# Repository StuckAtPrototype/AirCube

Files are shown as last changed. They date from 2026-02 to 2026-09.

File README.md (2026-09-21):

# AirCube

**See your air.** AirCube is a desktop air quality monitor with built-in **Home Assistant** support over **Zigbee** or **Bluetooth (BLE)**. Every model tracks temperature, humidity, eCO2, eTVOC, and VOC Level; AirCube Pro also measures true CO2 and ambient light. A glanceable LED shows the current air quality.

Works standalone out of the box. Pairs with Home Assistant in minutes. Other platforms are supported through **[community-contributed extensions](#community-extensions)**.

[AirCube Web](https://stuckatprototype.github.io/AirCube/) -- Live readings, history and firmware updates in your browser. Nothing to install.

[Watch the overview](https://www.youtube.com/watch?v=a4EFVtmDL8s) -- What AirCube does and why it's open source, in under three minutes.

[StuckAtPrototype Labs](https://www.youtube.com/@StuckAtPrototypeLabs) -- Step-by-step video walkthroughs: [ZHA setup](https://www.youtube.com/watch?v=rpkR3O64rY8), [Zigbee2MQTT setup](https://www.youtube.com/watch?v=eybU8-ZFDcc), and [updating firmware from the browser](https://www.youtube.com/watch?v=4XfEABJolAE).

[AirCube](https://stuckatprototype.com/products/aircube) -- Assembled AirCube

[AirCube Populated PCB](https://stuckatprototype.com/products/aircube-populated-pcb) -- AirCube Populated PCB

---

## Getting Started

**1. Plug it in** -- Connect the USB-C cable to any USB port or charger. AirCube powers on automatically.

**2. Wait for warm-up** -- The air quality sensor needs about 3 minutes to stabilize after power-on. During this time, the LED may not reflect accurate readings.

**3. Read the color** -- Once warmed up, the LED tells you everything:

| LED Color | Air Quality |
|---|---|
| Green | Good |
| Yellow | Moderate |
| Orange | Poor |
| Red | Bad -- consider ventilating |

The color shifts smoothly as conditions change. No app needed -- just glance at it.

> **Firmware 1.5.0 and above** drive the LED from **canonical VOC Level** (TVOC-derived, absolute). The color is a smooth green-to-red gradient -- same feel as older firmware, but tied to fixed indoor-air bands instead of the relative AQI-S baseline. See **[LED Reference](#led-reference)** for the exact mapping. Firmware **1.4.3 and below** used the same gradient shape, but driven by **AQI-S** instead.

**4. Adjust brightness** -- Press the button to cycle through brightness levels.

That's it. AirCube works out of the box with no setup, no accounts, and no Wi-Fi.

---

## Base vs. Pro

Both models use the ScioSense ENS161 for VOC Level, eCO2, and eTVOC. Choose **Pro** when you also want a direct CO2 measurement and automatic LED dimming based on room light.

| Feature | Base | Pro |
|---|---|-----|
| VOC Level, eCO2, and eTVOC | ENS161 | ENS161 |
| Temperature and humidity | ENS210 | Sensirion SCD41 |
| True CO2 | -- | Sensirion SCD41 (NDIR) |
| Ambient light | -- | VCNL4040 |
| Automatic LED dimming | -- | Yes |
| LED air-quality source | VOC Level | Whichever is worse: VOC Level or true CO2 |

> **eCO2 vs. true CO2:** eCO2 is an estimate derived from detected VOCs. The Pro's SCD41 measures CO2 directly using NDIR, while the ENS161 still detects odors and fumes that a pure CO2 sensor can miss.

## What AirCube Measures

| Measurement | Range | What It Tells You |
|---|---|---|
| **VOC Level** | 0 -- 500 | TVOC-derived score against fixed indoor-air bands (firmware 1.5.0+; 0--500 scale in 1.5.1+) |
| **AQI-S** (deprecated) | -- | Legacy relative VOC score. As of firmware 1.5.0 this always reports **0** over USB serial -- kept only for compatibility. Use VOC Level instead. |
| **eCO2** (equivalent CO2) | 400 -- 65,000 ppm | Estimated CO2 level derived from detected VOCs |
| **CO2** (Pro only) | 400 -- 5,000 ppm | True CO2 concentration from the SCD41 (direct NDIR measurement) |
| **eTVOC** (equivalent Total VOC) | 0 -- 65,000 ppb | Total volatile organic compound concentration |
| **Temperature** | | Room temperature in Celsius |
| **Humidity** | 0 -- 100 % | Relative humidity percentage |
| **Illuminance** (Pro only) | | Ambient light in lux; also used to dim the LED automatically |

### Understanding the readings

AirCube Base uses a **ScioSense ENS161** gas sensor and an **ENS210** temperature/humidity sensor. AirCube Pro uses the ENS161 alongside an **SCD41** for true CO2, temperature, and humidity, plus a **VCNL4040** ambient light sensor.

**eCO2 (ppm)** -- Estimated CO2 derived from detected VOCs, not a direct CO2 measurement. Useful for judging ventilation; also picks up odors and fumes a pure CO2 sensor would miss.

**eTVOC (ppb)** -- Total volatile organic compounds in the air. Spikes after cooking or cleaning are normal; sustained high readings mean you should ventilate.

**VOC Level (0--500)** -- TVOC mapped to a fixed indoor-air scale (firmware 1.5.1+). Linear ramp between band edges; TVOC-only (eCO2 does not affect VOC Level). Reported over Zigbee and USB serial.

| Rating | LED color | VOC Level | TVOC (ppb) |
|---|---|-----|---|
| Excellent | Green | 0 -- 15 | 0 -- 65 |
| Good | Green → lime | 15 -- 50 | 65 -- 220 |
| Moderate | Lime → yellow | 50 -- 100 | 220 -- 650 |
| Poor | Yellow → orange → red | 100 -- 200 | 650 -- 2,200 |
| Unhealthy | Red | 200 -- 500 | 2,200 -- 5,500 |

On Base hardware, the LED color is derived from TVOC/VOC Level alone (eCO2 does not drive the LED). VOC Level is linear between band edges, so the LED fades smoothly. See below for Pro's CO2 arbitration.

**AQI-S (deprecated, USB serial only)** -- A legacy ScioSense relative score from firmware before 1.5.0. As of firmware 1.5.0, AQI-S is deprecated and always reports **0** -- it's kept in the serial output only for compatibility with older tools. Use **VOC Level**, **eCO2**/**eTVOC**, or true **CO2** (Pro) instead.

**VOC Level** drives the LED color on Base hardware. On **Pro**, the LED shows whichever is worse -- VOC Level or CO2 Level (from the true CO2 reading). See **[LED Reference](#led-reference)**.

### Warm-up and initial start-up

The ENS161 needs about **3 minutes** of warm-up in standard mode before readings stabilize. On the very first power-on of a new sensor the initial start-up takes about **1 hour** as the sensor conditions itself. Readings during these periods may be inaccurate -- the LED and status flag will indicate when the sensor is ready.

---

## Built-in vs. community

**Maintained by StuckAtPrototype:** firmware, hardware, desktop app, and the **Home Assistant** integration documented in **[HOME_ASSISTANT.md](HOME_ASSISTANT.md)**.

**Community-contributed:** integrations built and shared by the community. They live in this repo and are welcome, but StuckAtPrototype does not test or ship them. They may require extra setup and can break when a vendor updates their platform. See **[Community extensions](#community-extensions)**.

---

## Home Assistant Integration

AirCube was designed for Home Assistant. It connects over **Zigbee** -- no USB cable to your server, no cloud, no Wi-Fi credentials to configure. Plug it in, hold the button for 3 seconds to start pairing, and six core entities show up: temperature, humidity, eCO2, eTVOC, VOC Level, and brightness.

**AirCube Pro** adds two more: **true CO2** (SCD41) and **illuminance** (VCNL4040). Both are exposed in **ZHA** and **Zigbee2MQTT 2.x** -- eight entities total on a Pro.

Once connected you can:
- **Track air quality over time** with built-in history graphs
- **Set up automations** -- turn on a fan when eCO2 gets too high, send a notification when VOC Level spikes
- **Monitor every room** -- each AirCube pairs independently, name them however you like

**You'll need:** a Zigbee coordinator dongle (we recommend the [SONOFF ZBDongle-E](https://sonoff.tech/product/gateway-and-sensors/sonoff-zigbee-3-0-usb-dongle-plus-e/), ~$13) plugged into your Home Assistant machine.

**Works with** ZHA (built-in) and Zigbee2MQTT.

**Video walkthroughs:** [Set up AirCube with ZHA](https://www.youtube.com/watch?v=rpkR3O64rY8) · [Set up AirCube with Zigbee2MQTT](https://www.youtube.com/watch?v=eybU8-ZFDcc)

**Full setup guide:** **[Connecting AirCube to Home Assistant](HOME_ASSISTANT.md)**

### No Zigbee dongle? AirCube also works over Bluetooth

AirCube boots into **BLE mode** by default (until you pair it to Zigbee) and broadcasts standard
**BTHome** data -- temperature, humidity, CO2, and TVOC. If your Home Assistant instance has a
Bluetooth adapter or an [ESPHome Bluetooth proxy](https://esphome.io/components/bluetooth_proxy.html)
nearby, it can often pick up these readings passively, with no pairing step and no Zigbee hardware
at all. Building a custom BLE client? See the **[BLE GATT Protocol reference](docs/BLE_GATT_PROTOCOL.md)**.

---

## Community extensions

The integrations below are **community-contributed**. They are not maintained by StuckAtPrototype and compatibility with vendor hub or app updates is not guaranteed.

### SmartThings (Samsung Zigbee hub) — community-contributed

Some users run AirCube on a **Samsung SmartThings** Zigbee hub over **Zigbee** (no Wi-Fi configuration on the device). The hub must support **SmartThings Edge**.

By default, the SmartThings app may only show **temperature** and **humidity** until you install the community **AirCube Zigbee** Edge driver from this repository and assign it to the device.

**Full setup guide:** **[Connecting AirCube to SmartThings](SMARTTHINGS.md)** (pairing, SmartThings CLI, driver channel, verification in the app and [Advanced Web App](https://my.smartthings.com/advanced)).

**Troubleshooting:** If you only see temperature and humidity, install the **AirCube Zigbee** Edge driver from [`smartthings/aircube-zigbee/`](smartthings/aircube-zigbee/) and assign it to the device. Details are in **[SMARTTHINGS.md](SMARTTHINGS.md)**.

---

## Connect to Your Computer

Plug the AirCube into your computer with a **data-capable USB-C cable** to see live readings, charts, and history.

### In your browser -- nothing to install

**[AirCube Web](https://stuckatprototype.github.io/AirCube/)** connects over USB straight from Chrome or Edge: live readings, LED brightness, history with CSV export, and firmware updates. Click **Connect**, pick your cube, and you're in.

### Download the app

Check the [Releases](https://github.com/StuckAtPrototype/AirCube/releases) page for a ready-to-run Windows `.exe` -- no install required.

### Or run from source

```
git clone https://github.com/StuckAtPrototype/AirCube.git
cd AirCube/scripts
pip install -r requirements.txt
python aircube_app.py
```

Select your serial port, click **Connect**, and you'll see live data.

> **Tip:** Prefer a minimal taskbar-only view? See the companion [**AirCube Tray**](https://github.com/StuckAtPrototype/AirCubeTray) repo -- a lightweight Windows system-tray app that shows VOC Level as a live, color-coded number in your taskbar. It ships its own installer.

---

## Firmware Updates

The current firmware is **v2.0.7**. It keeps the cube responsive when plugged into a charger or closed port, and on Pro units it disables SCD41 automatic self-calibration (replaced by a 425 ppm fresh-air calibration) and detects a CO2 channel that has stopped reporting. See the [v2.0.7 release notes](releases/RELEASE_NOTES_v2.0.7.md).

**[Flash it now with AirCube Web](https://stuckatprototype.github.io/AirCube/)** or read the **[Firmware Update Guide](FIRMWARE_UPDATE.md)** for step-by-step instructions.

**Video walkthrough:** [Updating the AirCube is easy (web UI)](https://www.youtube.com/watch?v=4XfEABJolAE) -- under two minutes, start to finish.

All releases: [GitHub Releases](https://github.com/StuckAtPrototype/AirCube/releases)

---

## Assembling Your AirCube

Building one yourself from printed parts and a populated PCB? All you need is three M2 x 5 mm screws and a small Phillips screwdriver -- about ten minutes of work.

**[Assembly Guide](ASSEMBLY.md)** -- photo walkthrough for both Base and Pro.

Printable enclosure files live in [`mechanical/base/`](mechanical/base) and [`mechanical/pro/`](mechanical/pro).

---

## LED Reference

### Firmware 1.5.0 and above

The LED is a continuous green-to-red gradient driven by **canonical VOC Level** (TVOC-derived). The hue moves linearly with VOC Level: pure green up to VOC Level 10, then fading green → lime → yellow → orange → red, reaching full red at VOC Level 200. eCO2 does **not** affect the LED.

```mermaid
flowchart LR
    A["VOC Level 0–10<br/>TVOC 0–~43 ppb"] --> G["Steady green"]
    B["VOC Level 10–200<br/>TVOC ~43–2 200 ppb"] --> GR["Green → lime → yellow → orange → red"]
    C["VOC Level 200+<br/>TVOC 2 200+ ppb"] --> R["Steady red"]
```

| LED color | VOC Level | TVOC (ppb) | Rating |
|---|-----|---|---|
| Steady green | 0 -- 10 | 0 -- ~43 | Excellent |
| Green → lime | 10 -- 50 | ~43 -- 220 | Good |
| Lime → yellow | 50 -- 100 | 220 -- 650 | Moderate |
| Yellow → orange → red | 100 -- 200 | 650 -- 2 200 | Poor |
| Steady red | 200+ | 2 200+ | Unhealthy |
| Flashing blue | -- | -- | Zigbee pairing mode |

Key gradient landmarks: **yellow** around VOC Level 105 (~730 ppb) and **orange** around VOC Level 150 (~1,460 ppb). Over **Zigbee**, TVOC-derived VOC Level is reported alongside eCO2, eTVOC, temperature, humidity, and brightness. **AQI-S** is deprecated, always reports 0, and does not drive the LED.

**On Pro hardware**, the LED shows whichever reading is worse: VOC Level (as above) or **CO2 Level**, a
0--500 score derived from the true SCD41 CO2 reading using the same band scale. If CO2 Level is
higher than VOC Level, the LED reflects the CO2 reading instead. On **Base** hardware, CO2 Level is
always 0, so VOC Level always drives the LED.

### Firmware 1.4.3 and below (legacy)

Same gradient shape as above, but driven by **AQI-S** (relative, 24-hour baseline) instead of canonical VOC Level:

| LED | Meaning |
|-----|---|
| Steady green | Good air quality (AQI-S 0--10) |
| Yellow through red | Degrading to poor air quality (AQI-S 10--200) |
| Steady red | Poor air quality (AQI-S 200+) |
| Flashing blue | Zigbee pairing mode |

### Button

| Action | What It Does |
|---|---|
| Short press | Cycle brightness (off, 10%, 30%, 60%, 100%) |
| Hold 3 seconds | Enter Zigbee pairing mode |

---

## Troubleshooting

**LED doesn't turn on**
- Make sure the USB-C cable is firmly connected and the power source is active.
- Try a different USB port or charger.

**Readings seem wrong right after power-on**
- Normal. The air quality sensor needs about 3 minutes to warm up. Readings will stabilize.

**Computer doesn't detect AirCube**
- Some USB cables are charge-only. Use a cable that supports data.
- Windows users may need to install [USB drivers](https://www.silabs.com/developers/usb-to-uart-bridge-vcp-drivers).
- Linux users: add yourself to the `dialout` group and re-login.

**Home Assistant: eCO2, TVOC, or VOC Level sensors are missing**
- The custom quirk or converter isn't loaded yet. See the [Home Assistant guide](HOME_ASSISTANT.md) for step-by-step instructions.

**Home Assistant: CO2 or Illuminance is missing (Pro)**
- These come from standard Zigbee clusters, so ZHA and Zigbee2MQTT 2.x pick them up without any extra configuration. If they're absent, confirm the unit is a Pro (Base has no SCD41 or VCNL4040), then remove and re-pair so the coordinator re-reads the endpoint. The legacy Zigbee2MQTT 1.x converter does not expose them.

**Home Assistant: AirCube won't pair**
- Make sure permit join is enabled in ZHA or Zigbee2MQTT.
- Hold the button for 3 seconds to enter pairing mode (LED flashes blue).
- Move AirCube closer to the coordinator during pairing.

---

## Open Source

AirCube is fully open source -- firmware, PCB design, enclosure, desktop software, and Home Assistant integration. Community-contributed integrations (see **[Community extensions](#community-extensions)**) also live in this repository. Everything is under the Apache 2.0 license.

**Developers and makers:** See the **[Contributing Guide](CONTRIBUTING.md)** for build instructions, architecture docs, serial protocol reference, and how to submit changes. Curious about the PCB? [These Holes Are Why My Circuit Board Works](https://www.youtube.com/watch?v=1yfeTHR3lqw) explains the cutouts in the board.

| | |
|---|---|
| [StuckAtPrototype Labs](https://www.youtube.com/@StuckAtPrototypeLabs) | Video walkthroughs: ZHA, Zigbee2MQTT, firmware updates |
| [Contributing Guide](CONTRIBUTING.md) | Build from source, firmware architecture, serial protocol, how to contribute |
| [Assembly Guide](ASSEMBLY.md) | Assemble the printed enclosure -- Base and Pro |
| [BLE GATT Protocol](docs/BLE_GATT_PROTOCOL.md) | BLE GATT protocol reference for building custom BLE clients |
| [Firmware Update Guide](FIRMWARE_UPDATE.md) | Update your AirCube firmware from a browser |
| [AirCube Web](web/) | The browser app: Web Serial monitoring, settings and flashing |
| [Home Assistant Guide](HOME_ASSISTANT.md) | ZHA and Zigbee2MQTT setup |
| [Samsung hub integration](SMARTTHINGS.md) | Community-contributed: Edge driver, CLI setup (see **[Community extensions](#community-extensions)**) |
| [GitHub Issues](https://github.com/StuckAtPrototype/AirCube/issues) | Bug reports and feature requests |
| [License](LICENSE) | Apache 2.0 |

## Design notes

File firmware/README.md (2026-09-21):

# AirCube Firmware

ESP-IDF firmware for the AirCube air quality monitor. Target chip: **ESP32-H2**.

For product documentation, integration guides, and the full architecture/build reference, see:

- [`../README.md`](../README.md) — product overview, sensor readings, LED behavior
- [`../CONTRIBUTING.md`](../CONTRIBUTING.md) — firmware architecture, module layout, serial protocol reference
- [`../FIRMWARE_UPDATE.md`](../FIRMWARE_UPDATE.md) — flashing a prebuilt binary over USB from the browser with AirCube Web
- [`../docs/BLE_GATT_PROTOCOL.md`](../docs/BLE_GATT_PROTOCOL.md) — BLE GATT protocol reference

## Build and flash

```
idf.py set-target esp32h2
idf.py build
idf.py -p PORT flash monitor
```

See [`../CONTRIBUTING.md`](../CONTRIBUTING.md) for prerequisites and a table of common build issues.

## AirCube Zigbee TX Power

AirCube exposes a build-time Zigbee TX power setting:

- `AirCube Configuration` -> `Zigbee TX power (dBm)` (`CONFIG_AIRCUBE_ZB_TX_POWER_DBM`)
- Default: `20 dBm` (the ESP32-H2's maximum output, for best link margin)
- Supported menuconfig range: `-24` to `20 dBm`

Set it with:

```
idf.py menuconfig
```

Then build and flash as usual. At boot, the firmware logs requested and applied TX power.

Lower values reduce range but can help in dense multi-device environments. Actual applied
power may be limited by hardware, SDK behavior, and regional regulatory limits — the firmware
logs a warning if the applied value doesn't match the requested one.

## Troubleshooting

Program upload failures and other build issues are covered in [`../CONTRIBUTING.md`](../CONTRIBUTING.md)'s
"Common build issues" table. For general ESP-IDF issues, run `idf.py -p PORT monitor` and reboot
the board to check for output logs, or lower the flashing baud rate in `idf.py menuconfig`.

For AirCube-specific bugs or feature requests, open a [GitHub issue](../CONTRIBUTING.md) on this repo.

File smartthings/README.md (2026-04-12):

# SmartThings Edge driver (Zigbee)

This folder contains the **AirCube Zigbee** Edge driver source for Samsung SmartThings hubs.

**User setup:** see **[SMARTTHINGS.md](../SMARTTHINGS.md)** in the repository root for step-by-step pairing, CLI install, channel workflow, and verification in the app and [Advanced Web App](https://my.smartthings.com/advanced).

**Layout**

```text
smartthings/
├── README.md                 # This file
├── driver-channel.json       # Input for `edge:channels:create -i` (TOS URL preset)
└── aircube-zigbee/           # Driver package (config, fingerprints, profile, Lua)
    ├── config.yml
    ├── fingerprints.yml
    ├── profiles/
    └── src/
```

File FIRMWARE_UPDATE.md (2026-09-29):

# AirCube Firmware Update Guide

Update your AirCube from the browser with [AirCube Web](https://stuckatprototype.github.io/AirCube/). It talks to the cube over USB using the Web Serial API, so there is nothing to install -- and once you are connected you also get live readings, the LED brightness control and your history, the same as the desktop app.

**Prefer to watch?** [Updating the AirCube is easy (web UI)](https://www.youtube.com/watch?v=4XfEABJolAE) shows the whole process in under two minutes.

## Prerequisites

- **Browser:** Google Chrome or Microsoft Edge (Safari and Firefox do not support Web Serial)
- **OS:** Windows, macOS, Linux, or ChromeOS
- **Cable:** A data-capable USB-C cable (charge-only cables won't work)

## Step-by-Step

### 1) Open AirCube Web

Go to [stuckatprototype.github.io/AirCube](https://stuckatprototype.github.io/AirCube/).

### 2) Connect your AirCube

1. Plug the USB-C cable into your AirCube and your computer.
2. Close anything else that might be holding the serial port (AirCube Tray, Arduino Serial Monitor, `idf.py monitor`).
3. Click **+ Connect** and pick your AirCube from the browser's device prompt. It appears as "USB JTAG/serial debug unit" or similar.

With one cube connected the app opens straight to its page and starts showing live readings.

### 3) Flash the firmware

1. Open the **⋯** menu on the device page and choose **Flash firmware**. (You can also reach it from Settings → Firmware.)
2. Pick the version you want. The newest release is marked **(latest)**.
3. Leave the flash offset at **0x0 (merged release image)**.
4. Click **Flash** and watch the log. It takes about 30 seconds.

The cube reboots itself when the write finishes and reconnects automatically. The LED should light up green after a few seconds.

Your settings -- brightness level and Zigbee pairing -- are preserved across firmware updates.

## Flashing a development build

If you built the firmware yourself with `idf.py build`, you have two options:

- Flash `build/AirCube.bin` (the app only) at offset **0x10000**.
- Or run `esptool merge-bin` first and flash the merged image at **0x0**.

Use the **Local .bin** button in the flash dialog to pick the file, then choose the matching offset.

## Troubleshooting

- **No device in the connect dialog:** Make sure another app isn't using the serial port. Try a different USB port or cable. On some USB-C cables, flipping the connector helps.
- **Browser not supported:** Use Chrome or Edge on a desktop OS. Safari and Firefox do not implement Web Serial, and iOS browsers cannot access USB devices at all.
- **"Failed to open serial port":** Another tab or application already has it. Close AirCube Tray and any serial monitors, then click Refresh in the dialog.
- **Flashing fails partway:** Unplug the AirCube, plug it back in, and try again. The bootloader is only reached at reset, so a fresh power cycle usually clears it.
- **Charge-only cable:** Some USB-C cables carry power but no data. Use the same cable that works with the desktop app.
- **Linux:** If the device never appears, your user may need permission for the ESP USB device. Add a udev rule for `303a:1001` or add yourself to the `dialout` group, then replug.
- **The cube doesn't reconnect after flashing:** Unplug and replug the USB-C cable, then click Connect again.
- **"Firmware update needed" banner, brightness and history unavailable:** The cube is running firmware from before February 2026 (shipped through January 2026). That firmware streams readings over USB but does not listen for commands on it, so only live readings work until it is updated. Click **Update firmware** on the banner; flashing works on these units because the bootloader, not the firmware, handles the transfer. If the flash does not start, unplug the cube, plug it back in and click **Update firmware** again straight away. AirCube Tray can hang on these units; use the web app to update them.

## Alternatives

- **[AirCube Tray](https://github.com/StuckAtPrototype/AirCubeTray)** -- the Windows desktop app, which can also flash over USB.
- **[ESP Launchpad](https://espressif.github.io/esp-launchpad/)** -- Espressif's generic web flasher. Use the **DIY** tab, add the `.bin` from [Releases](https://github.com/StuckAtPrototype/AirCube/releases), and set the flash address to `0x0`.
- **esptool** -- `esptool --chip esp32h2 -p PORT write-flash 0x0 AirCube_firmware_vX.Y.Z.bin`

## Success

After it reboots, the AirCube LED lights up and begins showing air quality colors within a few seconds. The gas sensor needs about 3 minutes to warm up before readings stabilize.

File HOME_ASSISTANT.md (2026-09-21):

# Connecting AirCube to Home Assistant

This guide walks you through adding your AirCube air quality monitor to Home Assistant over Zigbee. After setup, you'll have live temperature, humidity, eCO2, eTVOC, and VOC Level readings plus a brightness slider in your smart home dashboard. On an **AirCube Pro** you also get true CO2 and illuminance.

The AirCube works with both **ZHA** (built-in) and **Zigbee2MQTT**. Pick whichever you already use. If you're starting fresh, ZHA is simpler.

**Prefer to follow along?** Both methods have a step-by-step video on the [StuckAtPrototype Labs](https://www.youtube.com/@StuckAtPrototypeLabs) channel:

- [AirCube Home Assistant ZHA Walkthrough](https://www.youtube.com/watch?v=rpkR3O64rY8) -- includes installing the ZHA integration and the File editor
- [AirCube Home Assistant Z2M Walkthrough](https://www.youtube.com/watch?v=eybU8-ZFDcc)

> **A note on names.** Home Assistant renamed a couple of things in 2026.2, so the menus below are listed with both names -- use whichever your version shows:
>
> | HA 2026.2 and newer | HA 2026.1 and earlier |
> |---------------------|-----------------------|
> | **Apps** / **App Store** | **Add-ons** / **Add-on Store** |
> | **Settings > Zigbee** | **Settings > Devices & Services > ZHA** |
>
> Nothing functional changed -- only the labels. The integration is still called **Zigbee Home Automation (ZHA)** in the Add Integration list.

---

## What You Need

- **AirCube** -- powered via USB-C
- **Zigbee coordinator dongle** -- plugs into your Home Assistant machine
- **Home Assistant** -- running on any supported hardware (Raspberry Pi, mini PC, etc.)

### Recommended Zigbee Coordinators

Any Zigbee 3.0 coordinator works. If you don't have one yet, the **SONOFF ZBDongle-E** is the easiest to get started with (~$13).

| Dongle | Notes |
|---|---|
| SONOFF ZBDongle-E | Best value, widely available |
| SONOFF ZBDongle-P | Proven, large community |
| ConBee II / III | Also works, popular alternative |

---

# Method A -- ZHA (Recommended)

Use this method if you're using Home Assistant's built-in **Zigbee Home Automation** integration (the default). No extra apps (add-ons) required.

**Video:** [AirCube Home Assistant ZHA Walkthrough](https://www.youtube.com/watch?v=rpkR3O64rY8) covers every step below.

## A1 -- Set Up ZHA

If you already have ZHA running with your coordinator, skip to A2.

1. Plug your Zigbee coordinator dongle into your Home Assistant machine.
2. Go to **Settings > Devices & Services > Add Integration**.
3. Search for **Zigbee Home Automation (ZHA)** and add it.
4. Select your coordinator from the serial port list and follow the prompts.

## A2 -- Add the AirCube Quirk

The AirCube uses a custom Zigbee cluster (0xFC01) for air quality data and a standard Analog Output cluster (0x000D) for LED brightness. The quirk below tells ZHA to create **sensor entities** for eCO2, eTVOC, and VOC Level, plus a **brightness slider** (0--100%).

1. Install the **File editor** app (add-on) if you don't have it:
   - **Settings > Apps > App Store** (**Settings > Add-ons > Add-on Store** on HA 2026.1 and earlier) -- search **File editor**, install, start it.

2. Open **File editor** from the sidebar.

3. Create a folder called **`custom_zha_quirks`** **next to your `configuration.yaml`**.

   > **Where do I create it?** Open the File editor and look for `configuration.yaml`. On **HA 2026.x** it's in `/homeassistant/`, on **HA 2025.x and earlier** it's in `/config/`. Create `custom_zha_quirks` in whichever folder contains your `configuration.yaml`. **Do not** create a new folder called `config` -- just put `custom_zha_quirks` directly alongside `configuration.yaml`.

4. Inside `custom_zha_quirks`, create a new file called **`aircube.py`** and paste this content.
   This is kept in sync with [`zha/aircube.py`](zha/aircube.py) in this repo -- if you'd rather not
   copy/paste, you can grab the file directly from there instead.

```python
"""StuckAtPrototype AirCube air quality monitor quirk for ZHA.

This single file is compatible with both old and new Home Assistant:

  * Modern HA (zigpy >= 0.65.1, i.e. HA >= ~2024.8):
        Full quirks v2 support. Exposes eCO2, tVOC and AQI sensors from the
        custom 0xFC01 cluster plus a Brightness number on the Analog Output
        cluster.

  * Old HA (zigpy < 0.65, e.g. HA 2024.1.x):
        `zigpy.quirks.v2` does not exist yet, so importing QuirkBuilder raises
        ImportError and the whole quirk fails to load. We fall back to a classic
        v1 quirk so the module imports cleanly and the device is named correctly.

        IMPORTANT: on these old ZHA versions there is no supported way to turn
        custom-cluster (0xFC01) attributes into entities -- eCO2/tVOC/AQI will
        NOT appear until HA is updated to a version with quirks v2, or the values
        are read over BLE via the firmware's BTHome broadcaster. Temperature,
        humidity and brightness still work on old HA because they use standard
        Zigbee clusters and are discovered automatically.
"""

from zigpy.quirks import CustomCluster
from zigpy.zcl.foundation import ZCLAttributeDef
import zigpy.types as t

class AirQualityCluster(CustomCluster):
    """AirCube custom air quality cluster (0xFC01) — read-only sensors."""

    cluster_id = 0xFC01
    name = "AirCube Air Quality"
    ep_attribute = "aircube_air_quality"

    class AttributeDefs(CustomCluster.AttributeDefs):
        eco2 = ZCLAttributeDef(
            id=0x0000, type=t.uint16_t, is_manufacturer_specific=False
        )
        etvoc = ZCLAttributeDef(
            id=0x0001, type=t.uint16_t, is_manufacturer_specific=False
        )
        aqi = ZCLAttributeDef(
            id=0x0002, type=t.uint16_t, is_manufacturer_specific=False
        )

ANALOG_OUTPUT_CLUSTER_ID = 0x000D

# ---------------------------------------------------------------------------
# Detect whether this HA/zigpy version supports the quirks v2 API.
# ---------------------------------------------------------------------------
try:
    from zigpy.quirks.v2 import QuirkBuilder
    from zigpy.quirks.v2.homeassistant import EntityType

    try:
        from zigpy.quirks.v2.homeassistant.sensor import (
            SensorDeviceClass,
            SensorStateClass,
        )
    except ImportError:
        from homeassistant.components.sensor import (
            SensorDeviceClass,
            SensorStateClass,
        )

    _HAS_QUIRKS_V2 = True
except ImportError:
    _HAS_QUIRKS_V2 = False

if _HAS_QUIRKS_V2:
    # -----------------------------------------------------------------------
    # Modern HA: full quirks v2 definition.
    # -----------------------------------------------------------------------
    (
        QuirkBuilder("StuckAtPrototype", "AirCube")
        .replaces(AirQualityCluster, endpoint_id=10)
        .sensor(
            AirQualityCluster.AttributeDefs.eco2.name,
            AirQualityCluster.cluster_id,
            endpoint_id=10,
            unit="ppm",
            translation_key="equivalent_co2",
            state_class=SensorStateClass.MEASUREMENT,
            fallback_name="Equivalent CO2",
        )
        .sensor(
            AirQualityCluster.AttributeDefs.etvoc.name,
            AirQualityCluster.cluster_id,
            endpoint_id=10,
            unit="ppb",
            device_class=SensorDeviceClass.VOLATILE_ORGANIC_COMPOUNDS_PARTS,
            state_class=SensorStateClass.MEASUREMENT,
            fallback_name="tVOC",
        )
        .sensor(
            AirQualityCluster.AttributeDefs.aqi.name,
            AirQualityCluster.cluster_id,
            endpoint_id=10,
            state_class=SensorStateClass.MEASUREMENT,
            translation_key="voc_level",
            fallback_name="VOC Level",
        )
        .number(
            "present_value",
            ANALOG_OUTPUT_CLUSTER_ID,
            endpoint_id=10,
            min_value=0,
            max_value=100,
            step=1,
            mode="slider",
            entity_type=EntityType.STANDARD,
            translation_key="brightness",
            fallback_name="Brightness",
        )
        .add_to_registry()
    )
else:
    # -----------------------------------------------------------------------
    # Old HA (no quirks v2): classic v1 fallback.
    #
    # This keeps the module importable (stops the ImportError crash) and names
    # the device. Temperature, humidity and brightness are exposed by ZHA's
    # standard discovery. The eCO2/tVOC/AQI values on cluster 0xFC01 cannot be
    # surfaced as entities on this ZHA version -- update HA, or read them over
    # BLE (BTHome), for those.
    # -----------------------------------------------------------------------
    from zigpy.quirks import CustomDevice
    from zigpy.profiles import zha
    from zigpy.zcl.clusters.general import AnalogOutput, Basic, Identify
    from zigpy.zcl.clusters.measurement import (
        RelativeHumidity,
        TemperatureMeasurement,
    )
    from zhaquirks.const import (
        DEVICE_TYPE,
        ENDPOINTS,
        INPUT_CLUSTERS,
        MODELS_INFO,
        OUTPUT_CLUSTERS,
        PROFILE_ID,
    )

    class AirCube(CustomDevice):
        """AirCube v1 quirk for HA versions without quirks v2."""

        signature = {
            MODELS_INFO: [("StuckAtPrototype", "AirCube")],
            ENDPOINTS: {
                # <SimpleDescriptor endpoint=10 profile=260 device_type=770
                #  input_clusters=[0, 3, 13, 1026, 1029, 64513]
                #  output_clusters=[]>
                10: {
                    PROFILE_ID: zha.PROFILE_ID,
                    DEVICE_TYPE: zha.DeviceType.TEMPERATURE_SENSOR,
                    INPUT_CLUSTERS: [
                        Basic.cluster_id,
                        Identify.cluster_id,
                        AnalogOutput.cluster_id,
                        TemperatureMeasurement.cluster_id,
                        RelativeHumidity.cluster_id,
                        AirQualityCluster.cluster_id,
                    ],
                    OUTPUT_CLUSTERS: [],
                },
            },
        }

        replacement = {
            ENDPOINTS: {
                10: {
                    PROFILE_ID: zha.PROFILE_ID,
                    DEVICE_TYPE: zha.DeviceType.TEMPERATURE_SENSOR,
                    INPUT_CLUSTERS: [
                        Basic,
                        Identify,
                        AnalogOutput,
                        TemperatureMeasurement,
                        RelativeHumidity,
                        AirQualityCluster,
                    ],
                    OUTPUT_CLUSTERS: [],
                },
            },
        }
```

5. Open your main **`configuration.yaml`** (in `/config/`) and add:

   ```yaml
   zha:
     custom_quirks_path: /config/custom_zha_quirks/
     enable_quirks: true
   ```

   > **Note:** Use `/config/custom_zha_quirks/` exactly as shown -- this path works on **both** HA 2025.x and 2026.x, even though the File editor in 2026.x shows the root as `/homeassistant/`. The trailing `/` is required on HA 2026.x. **Do not** change `/config/` to `/homeassistant/` in this setting.

   If you already have a `zha:` section, just add the two lines underneath it.

6. **Restart Home Assistant** from **Settings > System > Restart**.
7. **Remove and re-pair** the AirCube once after adding the quirk (ZHA caches device data at first join).

## A3 -- Pair the AirCube

1. Go to **Settings > Zigbee** (**Settings > Devices & Services > ZHA** on HA 2026.1 and earlier).
2. Click **Add Device**.
3. **Plug in your AirCube** via USB-C. It boots into BLE mode by default -- Zigbee pairing is not automatic.
4. **Hold the button on the AirCube for 3 seconds.** The LEDs will start flashing blue, and the device reboots into Zigbee mode to begin network steering.
5. Wait 10-30 seconds. The AirCube will appear in ZHA. Give it a name like `AirCube Living Room`.
6. When the LEDs stop flashing blue and return to a steady color, pairing is complete.

## A4 -- Verify Sensors

Go to **Settings > Zigbee > Devices** (**Settings > Devices & Services > ZHA** on HA 2026.1 and earlier) and click on the AirCube device. You should see six entities:

| Entity | What It Does | Unit |
|---|---|---|
| Temperature | Room temperature | C |
| Humidity | Relative humidity | % |
| Equivalent CO2 | eCO2 concentration (estimated) | ppm |
| tVOC | eTVOC concentration | ppb |
| VOC Level | TVOC-derived VOC Level (0--500) | -- |
| Brightness | LED brightness (slider) | 0--100 |

> Temperature and humidity are detected automatically by ZHA. eCO2, eTVOC, and VOC Level come from the custom quirk. The brightness slider uses the standard Analog Output cluster.

**AirCube Pro** shows two more entities, for eight total:

| Entity | What It Does | Unit |
|---|---|---|
| Carbon dioxide | True CO2 from the SCD41 (direct NDIR measurement) | ppm |
| Illuminance | Ambient light from the VCNL4040 | lx |

> These use the standard Zigbee CO2 (0x040D) and Illuminance (0x0400) clusters, so ZHA discovers them on its own -- the quirk doesn't need to do anything. They only exist on Pro hardware; a Base has neither sensor. Exact entity labels can vary slightly between Home Assistant versions.

---

# Method B -- Zigbee2MQTT

Use this method if you prefer Zigbee2MQTT or already have it running.

**Video:** [AirCube Home Assistant Z2M Walkthrough](https://www.youtube.com/watch?v=eybU8-ZFDcc) covers every step below.

## B1 -- Install MQTT Broker

1. Go to **Settings > Apps > App Store** (**Settings > Add-ons > Add-on Store** on HA 2026.1 and earlier).
2. Search for **Mosquitto broker**, click **Install**, then **Start**.
3. Go to **Settings > Devices & Services > Add Integration**.
4. Search for **MQTT** and add it. Accept the defaults.

## B2 -- Install Zigbee2MQTT

1. Go to **Settings > Apps > App Store** (**Settings > Add-ons > Add-on Store** on HA 2026.1 and earlier).
2. Click the **three-dot menu** (top-right) > **Repositories**.
3. Add this URL:
   ```
   https://github.com/zigbee2mqtt/hassio-zigbee2mqtt
   ```
4. Search for **Zigbee2MQTT** and click **Install**.

## B3 -- Plug In Your Coordinator

1. Plug the Zigbee dongle into your Home Assistant machine.
2. Go to **Settings > System > Hardware** > three-dot menu > **All Hardware**.
3. Find your dongle. Write down its path (e.g. `/dev/ttyACM0`).

## B4 -- Configure and Start Zigbee2MQTT

1. Go to **Settings > Apps > Zigbee2MQTT > Configuration** tab (**Settings > Add-ons > ...** on HA 2026.1 and earlier).
2. Set the serial port:
   ```yaml
   serial:
     port: /dev/ttyACM0
   ```
3. Enable **Start on boot** and **Watchdog**, then click **Start**.

## B5 -- Add the AirCube Converter

The converter file format depends on your Zigbee2MQTT version:
- **Z2M 2.x** (2024+): Uses ES modules (`.mjs`)
- **Z2M 1.x** (legacy): Uses CommonJS (`.js`)

Both converter files are in the [`z2m/`](z2m/) folder of this repo.

### Z2M 2.x (Recommended)

1. Open **File editor** (install from the **App Store** / **Add-on Store** if needed).
2. Navigate to the `zigbee2mqtt` folder (the one containing `configuration.yaml`) and create an `external_converters` subfolder next to it.
3. Copy [`z2m/aircube.mjs`](z2m/aircube.mjs) into the `external_converters` folder.
4. Open **`configuration.yaml`** in the `zigbee2mqtt` folder and **enable external JavaScript**:

   ```yaml
   advanced:
     enable_external_js: true
   ```

   If you already have an `advanced:` section, just add the one line under it. **This step is required.** Zigbee2MQTT ships with external converters switched off, and when they are off Z2M never even looks in the `external_converters` folder -- you get no error, just a device with no custom sensors. There is an equivalent **Enable external JS** toggle in the Z2M web UI under **Settings > Advanced**.

5. In the same **`configuration.yaml`**, **remove** any `external_converters:` block if one is present:

   ```yaml
   # Delete these lines -- they break converter loading on Z2M 2.x
   external_converters:
     - external_converters/aircube.mjs
   ```

   Z2M 2.0 removed this setting. Everything inside the `external_converters` folder is now loaded automatically, and leaving the old setting in place stops the converter (and sometimes Z2M itself) from starting.

6. **Restart Zigbee2MQTT** from its app (add-on) page.
7. Check the Zigbee2MQTT log. You should see `Loaded external converter 'aircube.mjs'.` If you instead see `External JS (converters/extensions) is disabled`, step 4 did not take effect.

### Sample `configuration.yaml`

A complete, working Z2M 2.x config with the AirCube converter enabled. Yours will have different values for `network_key`, `port`, and your MQTT credentials -- copy the structure, not the secrets.

```yaml
mqtt:
  base_topic: zigbee2mqtt
  server: mqtt://core-mosquitto:1883
  user: your_mqtt_user
  password: your_mqtt_password

serial:
  port: /dev/ttyACM0

advanced:
  # Keep whatever network_key you already have. Changing it un-pairs every device.
  network_key: [1, 2, 3, 4, 5, 6, 7, 8, 9, 10, 11, 12, 13, 14, 15, 16]
  # Required for the AirCube converter. Off by default; nothing in
  # external_converters/ is read while this is false.
  enable_external_js: true

frontend:
  enabled: true
  port: 8099

homeassistant:
  enabled: true

devices:
  '0x1051dbfffe65fc77':
    friendly_name: AirCube Living Room
```

The converter itself is **not** referenced anywhere in this file. `aircube.mjs` just has to exist in the `external_converters` folder next to `configuration.yaml`.

Two mistakes that are easy to make here:

- **Do not add a second `advanced:` block.** If `enable_external_js: false` is already in your config, edit that line in place. YAML does not merge duplicate keys -- Z2M parses the file with `js-yaml`, which treats a repeated top-level key as a fatal error, so the bridge will refuse to start.
- **Do not add an `external_converters:` list.** That setting was removed in Z2M 2.0. Leaving it in place breaks converter loading.

### Z2M 1.x (Legacy)

1. Open **File editor**.
2. Copy [`z2m/aircube.js`](z2m/aircube.js) into the `zigbee2mqtt` folder.
3. Open **`configuration.yaml`** in the `zigbee2mqtt` folder and add:

   ```yaml
   external_converters:
     - aircube.js
   ```

4. **Restart Zigbee2MQTT** from its app (add-on) page.

## B6 -- Pair the AirCube

1. In the Zigbee2MQTT dashboard, click **Permit join (All)**.
2. **Plug in your AirCube** via USB-C (or hold the button 3 seconds if already plugged in).
3. Wait for the LEDs to stop flashing blue.
4. Name the device in Zigbee2MQTT (e.g. `AirCube Living Room`).

## B7 -- Verify Sensors

Go to **Settings > Devices & Services > MQTT** and click on the AirCube. You should see six entities:

| Entity | What It Does | Unit |
|---|---|---|
| Temperature | Room temperature | C |
| Humidity | Relative humidity | % |
| Equivalent CO2 | eCO2 concentration (estimated) | ppm |
| VOC parts | eTVOC concentration | ppb |
| VOC level | TVOC-derived VOC Level (0--500) | -- |
| Brightness | LED brightness (slider) | 0--100 |

On the **Pro**, two more entities appear from the dedicated sensors when using **Zigbee2MQTT 2.x with `aircube.mjs`**: **CO2** (true CO2 from the SCD41, in ppm) and **Illuminance** (ambient light from the VCNL4040, in lx). These are absent on the Base. The legacy Zigbee2MQTT 1.x `aircube.js` converter exposes only the six core entities.

> If the device card says *"Automatically generated definition"*, the converter did **not** load. See the troubleshooting section below.

---

# Dashboard

These cards work with both ZHA and Zigbee2MQTT.

### Quick Entities Card

Edit your dashboard, click **Add Card**, choose **Entities**, and select:
- AirCube Temperature
- AirCube Humidity
- AirCube Equivalent CO2
- AirCube tVOC
- AirCube VOC Level
- AirCube Brightness
- AirCube Carbon dioxide and AirCube Illuminance (Pro only)

### VOC Level Gauge

Add a **Manual card** and paste:

```yaml
type: gauge
entity: sensor.aircube_living_room_voc_level
name: Air Quality
min: 0
max: 500
severity:
  green: 0
  yellow: 50
  red: 200
```

### 24-Hour History

```yaml
type: history-graph
title: Air Quality - Last 24 Hours
hours_to_show: 24
entities:
  - entity: sensor.aircube_living_room_temperature
  - entity: sensor.aircube_living_room_humidity
  - entity: sensor.aircube_living_room_voc_level
```

> Entity names depend on what you named the device. Check **Settings > Devices & Services** for the exact entity IDs.

---

## LED Reference

The LED follows **canonical VOC Level** (TVOC-derived) on a continuous green-to-red gradient. The hue moves linearly with VOC Level, so the color fades smoothly rather than stepping between bands. eCO2 does **not** affect the LED.

| LED color | VOC Level | TVOC (ppb) | Rating |
|---|-----|---|---|
| Steady green | 0--10 | 0--~43 | Excellent |
| Green → lime | 10--50 | ~43--220 | Good |
| Lime → yellow | 50--100 | 220--650 | Moderate |
| Yellow → orange → red | 100--200 | 650--2,200 | Poor |
| Steady red | 200+ | 2,200+ | Unhealthy |
| Flashing blue | -- | -- | Pairing mode (searching for Zigbee network) |
| Off | -- | -- | Brightness set to 0 (press button to cycle) |

> On firmware **1.4.3 and below**, the same gradient was driven by **AQI-S** (relative) instead of canonical VOC Level. See the [README LED Reference](README.md#led-reference) for the full mapping.

### Button

| Action | Result |
|---|---|
| Short press | Cycle LED brightness (off, 10%, 30%, 60%, 100%) |
| Hold 3 seconds | Enter Zigbee pairing mode (LEDs flash blue) |

---

## Troubleshooting

### The AirCube LEDs flash blue but it never connects

- Make sure pairing/permit join is enabled in ZHA or Zigbee2MQTT.
- Move the AirCube closer to the coordinator. Zigbee works best within 10-30 meters indoors.
- Check that your coordinator is online in the integration dashboard.

### Temperature and humidity show up but eCO2 / eTVOC / VOC Level are missing

- The custom quirk (ZHA) or converter (Z2M) is not loaded.
- **ZHA:** Check that `custom_quirks_path` is set in `configuration.yaml` and the `aircube.py` file is in the right folder. The path in `configuration.yaml` must be `/config/custom_zha_quirks/` (not `/homeassistant/...`). Restart Home Assistant, then remove and re-pair the AirCube.
- **ZHA (HA 2026.x):** The File editor shows the root as `/homeassistant/` instead of `/config/`. **Do not** create a new folder called `config` inside `/homeassistant/`. Place `custom_zha_quirks` directly inside `/homeassistant/`, next to `configuration.yaml`. The path in `configuration.yaml` should still say `/config/custom_zha_quirks/`.
- **Firmware:** Make sure you are running the latest AirCube firmware from this repo. It actively sends attribute reports for the custom cluster so ZHA updates the sensors.
- **Firmware version:** The device reports its build as the Zigbee Basic cluster **Software build ID** (`sw_build_id`, attribute `0x4000` on cluster `0x0000`, endpoint `10`). In ZHA you can read it under the device’s **Manage Zigbee device** UI. The string comes from ESP-IDF’s app version (`firmware/version.txt` at build time).
- **Z2M 2.x:** Open the device page in Home Assistant. If it says **"Automatically generated definition"**, Z2M never loaded `aircube.mjs` and is guessing from the raw Zigbee clusters — which is why only the standard ones (temperature, humidity, CO2, illuminance, "Analog output 10") show up. The Z2M log tells you which failure it is; check, in order:
  - The log line **`External JS (converters/extensions) is disabled`** at startup. This is the most common cause. Set `advanced: enable_external_js: true` in `configuration.yaml` (see the [sample config](#sample-configurationyaml)) and restart. While it is disabled Z2M does not read the `external_converters` folder at all, so there is no error message about the converter — only a `Device ... is NOT supported` warning.
  - `aircube.mjs` sits in an `external_converters` folder **next to** `configuration.yaml` (on the HA app/add-on that is `/homeassistant/zigbee2mqtt/external_converters/`, **not** `.../data/external_converters/`). If the folder or filename is wrong, Z2M skips it silently.
  - There is **no** `external_converters:` block left in `configuration.yaml`. That setting was removed in Z2M 2.0 and its presence prevents loading.
  - You're using `aircube.mjs`, not `aircube.js` — Z2M 2.x requires ES module format. If Z2M renames the file to `aircube.mjs.invalid`, the converter has a load error; check the Z2M logs.
  - After fixing any of the above, restart Z2M and then **re-interview** the device (device page > *Reconfigure*) so the custom cluster is registered.
- **Z2M 1.x:** Check that `external_converters` is in the Z2M `configuration.yaml` and `aircube.js` is in the `zigbee2mqtt` folder. Restart Zigbee2MQTT.

### CO2 or Illuminance is missing (Pro)

- These two entities come from **standard** Zigbee clusters, not the custom one, so they don't depend on the quirk or converter. ZHA and Zigbee2MQTT 2.x pick them up automatically.
- Confirm the unit is a **Pro**. A Base has no SCD41 or VCNL4040, so the firmware never declares those clusters.
- The clusters are read when the device first joins. If you flashed a Pro after pairing it, or the entities never appeared, **remove and re-pair** (ZHA) or **Reconfigure** the device (Z2M) so the coordinator re-reads the endpoint.
- **Z2M 1.x:** the legacy `aircube.js` converter does not expose these. Move to Z2M 2.x and `aircube.mjs`.

### eCO2 / eTVOC / VOC Level values are stuck at 0

This is normal for the first 5 minutes after power-on. The air quality sensor needs to warm up. Once ready, values will start updating (typically within 60 seconds).

### I want to pair the AirCube to a different Home Assistant

Hold the button for 3 seconds to re-enter pairing mode. If the device won't leave its old network, unplug it, plug it back in, and immediately hold the button for 3 seconds while it boots.

### Sensor values only update every 10 seconds

This is by design. The AirCube pushes new sensor values over Zigbee every 10 seconds. Additionally, the ZCL reporting configuration will send an immediate update when a reading changes significantly (temperature by 0.5 C, eCO2 by 50 ppm, VOC Level by 5 points, etc.).

### Can I use multiple AirCubes?

Yes. The quirk/converter applies to every AirCube automatically. Just pair each one and give it a unique name. Each gets its own set of sensors and brightness control.

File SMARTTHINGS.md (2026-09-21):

# Connecting AirCube to SmartThings (Samsung hub)

This guide walks you through pairing AirCube to a **SmartThings-compatible Zigbee hub** and installing the community **AirCube Zigbee** Edge driver so you get **temperature, humidity, eCO2, eTVOC, and VOC Level** in the SmartThings app.

> **Default behavior:** Without this driver, SmartThings often joins AirCube as a generic **humidity / temperature** device. You only get **temp and humidity**. The Edge driver adds the **air quality** sensors over Zigbee cluster `0xFC01` (same idea as the [ZHA quirk](zha/aircube.py) and [Zigbee2MQTT converter](z2m/aircube.mjs)).

**You will need**

- AirCube powered over USB-C
- A **SmartThings Edge**–capable hub (e.g. SmartThings v3, Aeotec Smart Home Hub, SmartThings Station) on your Samsung account
- A **Mac, Windows, or Linux PC** for the [SmartThings CLI](https://github.com/SmartThingsCommunity/smartthings-cli) (one-time driver install)
- A [Samsung account](https://account.samsung.com/) used with SmartThings

The first time the CLI needs your SmartThings account, it **starts a browser sign-in** automatically (you may not see a separate `login` subcommand in `smartthings --help`). You do **not** need to create a Personal Access Token in the developer portal for normal interactive use. For **automation / CI**, you can use a [PAT](https://developer.smartthings.com/docs/personal-access-tokens) with channel scopes — see [driver channels](https://developer.smartthings.com/docs/devices/hub-connected/driver-channels).

---

## Step 1 — Put AirCube in pairing mode

1. Plug in AirCube (or, if already powered, use the next step).
2. **Hold the button for about 3 seconds** until the LEDs **flash blue** (Zigbee pairing mode).

See the [README](README.md) LED / button table if you need a refresher.

---

## Step 2 — Add AirCube in the SmartThings mobile app

1. Open the **SmartThings** app → **Add device** (or **+**).
2. Choose **Scan nearby** / **Zigbee** / **Generic Zigbee device** per your app version, and enable **pairing** on the hub when prompted.
3. Wait until AirCube appears and finish naming / room assignment.

**Check:** Open the new device — you should see **temperature** and **humidity**.  
**eCO2, TVOC, and VOC Level will not appear yet** until the **AirCube Zigbee** driver is installed and selected (next steps).

---

## Step 3 — Install the SmartThings CLI (sign-in is automatic)

1. Install the CLI using the [official instructions](https://github.com/SmartThingsCommunity/smartthings-cli) for your OS (Homebrew on Mac: `brew install smartthings`).
2. Run `smartthings --version` and confirm the command works.

**Authentication:** Many recent builds do **not** list a `smartthings login` command. The **first command that calls the SmartThings API** (for example **`smartthings edge:drivers:package .`** in Step 5) will **open a browser** so you can sign in with your Samsung account. Complete that flow once; later CLI commands reuse the session.

- To **sign out** on this machine: `smartthings logout` (then the next API command will prompt for login again).
- **Optional:** Headless or automation-only setups can use a **Personal Access Token** instead; see [CLI authentication](https://developer.smartthings.com/docs/sdks/cli/).

---

## Step 4 — Get the Edge driver source

From your clone of **this repository** (folder name may differ):

```bash
cd smartthings/aircube-zigbee
```

If you have not cloned yet:

```bash
git clone https://github.com/StuckAtPrototype/AirCube.git
cd AirCube/smartthings/aircube-zigbee
```

That directory contains `config.yml`, `fingerprints.yml`, `profiles/`, and `src/init.lua`.

---

## Step 5 — Package the driver (build + upload)

From `smartthings/aircube-zigbee`:

```bash
smartthings edge:drivers:package .
```

The **first** time you run this (or any API command), the CLI may **open the browser** for Samsung sign-in — complete it, then re-run `package` if needed.

The CLI prints a **Driver Id** and **Version** (timestamp string). **Save both** — you need them to assign the driver to a channel.

Optional: also write a local zip:

```bash
smartthings edge:drivers:package . -b ./aircube-zigbee.zip
```

> Recent CLI versions **upload** the driver when you package; there is **no** separate `publish` command.

---

## Step 6 — Create a driver channel (first time only)

You need a **driver channel** to install your own driver on the hub.

This repo ships [`smartthings/driver-channel.json`](smartthings/driver-channel.json) for `edge:channels:create`. It points **`termsOfServiceUrl`** at the StuckAtPrototype **[Terms of Service](https://stuckatprototype.com/policies/terms-of-service)**. Edit **`name`** / **`description`** in that file if you want different labels on your channel.

From the **repository root** (the folder that contains `smartthings/`):

```bash
smartthings edge:channels:create -i smartthings/driver-channel.json
```

List channels and copy your **channel id** (UUID):

```bash
smartthings edge:channels
```

---

## Step 7 — Assign the packaged driver to your channel

```bash
smartthings edge:channels:assign <DRIVER_ID> "<VERSION>" --channel <CHANNEL_ID>
```

Use the **Driver Id** and **Version** from Step 5. You can omit arguments and use **interactive prompts** instead.

---

## Step 8 — Enroll your hub, then install the driver

**Order matters:** enroll the hub on the channel **before** install.

```bash
smartthings edge:channels:enroll --channel <CHANNEL_ID>
```

Pick your hub when prompted (or pass flags if your CLI supports them).

Then install the driver **onto that hub** from the same channel:

```bash
smartthings edge:drivers:install --channel <CHANNEL_ID> --hub <HUB_DEVICE_UUID>
```

### Hub id must be a UUID

`<HUB_DEVICE_UUID>` looks like `xxxxxxxx-xxxx-xxxx-xxxx-xxxxxxxxxxxx`. It is **not** the sticker MAC, Zigbee EUI, or `networkId` string.

**Where to find it**

- [SmartThings Advanced Web App](https://my.smartthings.com/advanced) → open your **hub** as a device → copy **Device id**, **or**
- Open any Zigbee child device (e.g. AirCube) → **Parent device** / hub → copy that hub’s id.

If you omit `--hub`, the CLI usually offers a **list** — picking from the list avoids typos.

If install returns **HTTP 400**, see [Troubleshooting](#troubleshooting) below.

---

## Step 9 — Use the AirCube Zigbee driver for your device

The hub must run **AirCube Zigbee** instead of the generic **Zigbee Humidity Sensor** driver.

**Option A — Switch driver (keep device / room)**

```bash
smartthings edge:drivers:switch <DEVICE_ID>
```

Use the AirCube **device** id from the Advanced Web App (not the hub id). Follow prompts to select **AirCube Zigbee**.

**Option B — Remove and re-pair**

Remove AirCube from SmartThings, then add it again (Step 2) **after** the driver is installed on the hub. With a matching fingerprint, SmartThings should pick **AirCube Zigbee** automatically.

---

## Step 10 — Confirm in the Advanced Web App

1. Open [SmartThings Advanced Web App](https://my.smartthings.com/advanced).
2. Select **AirCube**.
3. Check **Driver** (or device summary): it should show **AirCube Zigbee** (or your packaged driver name), not only “Zigbee Humidity Sensor”.
4. Under capabilities / state, you should eventually see **carbon dioxide**, **TVOC**, and **air quality** style attributes after reports arrive (allow a few minutes for sensor warm-up).

---

## Step 11 — Confirm in the mobile app

Open the device card: you should see **temperature**, **humidity**, **CO₂**, **TVOC**, and **air quality** (labels may vary slightly by app version).

Gas sensors may read **0** for the first few minutes after power-on — that is normal while the ENS16x warms up (same as [Home Assistant](HOME_ASSISTANT.md)).

---

## Troubleshooting

| Problem | What to try |
|---|---|
| Only temp / humidity | Driver not applied — repeat [Step 9](#step-9--use-the-aircube-zigbee-driver-for-your-device). |
| `drivers:install` **400 Bad Request** | Use **hub UUID**, not sticker id. Run **`channels:enroll`** for the same channel first. |
| eCO2 / TVOC / VOC Level stuck at 0 | Wait **3–5+ minutes** after power-on. Ensure driver is **AirCube Zigbee** and hub is **online**. |
| CLI / channel errors | Run `smartthings logout` then repeat the command that triggered login (browser). If you use a **PAT** instead, confirm it includes **channel** read/write. See [driver channels](https://developer.smartthings.com/docs/devices/hub-connected/driver-channels). |

---

## Technical reference

Zigbee layout (endpoint **10**): standard temp/humidity clusters; custom air quality cluster **`0xFC01`**; LED brightness uses Analog Output **`0x000D`** (not exposed in this driver v1). **AirCube Pro** additionally declares the standard CO2 (**`0x040D`**) and Illuminance (**`0x0400`**) clusters; this driver does not read them yet, so the app's **CO₂** tile shows eCO2 from `0xFC01` on both models. Details match [CONTRIBUTING.md](CONTRIBUTING.md) → *Zigbee Integration*.

---

## Contributors

If you improve the Edge driver or this guide, open a **pull request** on the [AirCube](https://github.com/StuckAtPrototype/AirCube) repository so all users get the update.

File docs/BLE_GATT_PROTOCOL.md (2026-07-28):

# AirCube BLE GATT Protocol (v1)

Protocol between an AirCube in **BLE mode** (its default radio mode when not
joined to a Zigbee network) and client apps (iOS app, future desktop BLE).
The firmware implements this in `firmware/main/ble_gatt.c`. The iOS client is
maintained in a separate repository — there is no `ios/` directory in this repo.

All multi-byte fields are **little-endian** (native ESP32 byte order).

## Advertising

| Packet | Contents |
|---|---|
| Advertisement (connectable) | Flags (0x06) + BTHome v2 service data (UUID 0xFCD2 — same payload format as the reference implementation in `ble_bthome.c`, so HA Bluetooth proxies keep working) |
| Scan response | Complete local name `AirCube` + 128-bit AirCube service UUID |

`ble_bthome.c` exists in the source tree as a standalone reference but is **not** part of the
current build (it's not listed in `firmware/main/CMakeLists.txt`). The live BTHome v2 payload is
generated inline by `ble_gatt.c`'s `do_advertise()`. This advertisement is only broadcast while
the device is in BLE mode — it stops once the device joins a Zigbee network.

iOS clients scan with `withServices: [AIRCUBE_SERVICE]`; CoreBluetooth matches
UUIDs from the scan response.

## Service and characteristics

Base UUID suffix: `-1D0F-4E7C-8E4B-2A3D5F6B7C80`

| UUID prefix | Name | Properties | Size |
|---|---|---|---|
| `A17C0DE0` | AirCube Service | — | — |
| `A17C0DE1` | Device Info | Read | 14 B |
| `A17C0DE2` | Live Data | Read, Notify | 20 B |
| `A17C0DE3` | History Request | Write | 4 B |
| `A17C0DE4` | History Data | Notify | ≤ MTU−3 |
| `A17C0DE5` | Brightness | Read, Write, Notify | 1 B |

Firmware prefers ATT MTU 256 (iOS typically negotiates 185).

## Device Info (`A17C0DE1`, read)

| Offset | Type | Field |
|---|---|---|
| 0 | u8 | protocol_version (= 1) |
| 1 | u8 | model: 0 = Base, 1 = Pro |
| 2 | u8 | fw_major |
| 3 | u8 | fw_minor |
| 4 | u8 | fw_patch |
| 5 | u8 | reserved (0) |
| 6 | u16 | history_capacity (2016) |
| 8 | u16 | history_entry_count (current valid entries) |
| 10 | u16 | history_window_s (300) |
| 12 | u16 | newest_seq (sequence of newest slot; 0xFFFF if history empty) |

## Live Data (`A17C0DE2`, read + notify)

Notified once per sensor readout (~1 s). 20 bytes:

| Offset | Type | Field |
|---|---|---|
| 0 | i16 | temperature, °C × 100 |
| 2 | u16 | humidity, % × 100 |
| 4 | u16 | VOC Level (0–500) |
| 6 | u16 | eCO2, ppm (ENS16X estimate) |
| 8 | u16 | eTVOC, ppb |
| 10 | u16 | CO2, ppm (SCD41 NDIR; 0 on Base) |
| 12 | u16 | ambient light, lux × 10 (VCNL4040; 0 on Base) |
| 14 | u8 | AQI-UBA (1–5) |
| 15 | u8 | flags: bit0 = Pro model |
| 16 | u32 | uptime, ms |

## Brightness (`A17C0DE5`, read + write + notify)

Single byte: LED brightness percent, 0–100 (writes above 100 are clamped).
Writes apply immediately and persist to NVS across reboots. The device
notifies the confirmed value after any brightness change — including local
ones (button press) and Zigbee writes — so subscribed clients stay in sync.

The hardware button cycles 0 → 10 → 30 → 60 → 100 → 0, snapping to the next
level above the current (possibly BLE-written) percent.

## History sync (streaming, not paged)

1. Client subscribes to **History Data** notifications.
2. Client writes a request to **History Request**:

| Offset | Type | Field |
|---|---|---|
| 0 | u8 | opcode: 0x01 = start stream, 0x02 = abort |
| 1 | u8 | reserved (0) |
| 2 | u16 | after_seq: stream only slots with sequence > this. 0xFFFF = full history |

3. Firmware streams **History Data** notifications back-to-back until caught
   up, then sends a done frame. No per-page round trips.

### History Data frames

Every frame starts with a 4-byte header:

| Offset | Type | Field |
|---|---|---|
| 0 | u8 | frame_type: 0x01 data, 0x02 done, 0x03 error |
| 1 | u8 | slot_count (data frames) / 0 |
| 2 | u16 | data: logical index of first slot in frame · done: total slots sent · error: reason code |

**Data frame** (0x01): header + `slot_count` × 32-byte slots. `slot_count`
is the largest n with `4 + 32n ≤ MTU−3` (5 slots at MTU 185).

**Done frame** (0x02): stream complete. The client anchors wall-clock time
now: newest slot = time of done frame; each older slot is `history_window_s`
earlier. Slots have no absolute timestamps (the device has no RTC).

**Error frame** (0x03) reason codes: 1 = busy (another history stream is
active, e.g. over USB serial — retry after a short delay), 2 = bad request.

### Slot binary layout (32 bytes, packed)

Matches `history_slot_t` in `firmware/main/history.h`:

| Offset | Type | Field |
|---|---|---|
| 0 | u16 | sequence (0xFFFF = empty/invalid slot, skip it) |
| 2 | i16 ×3 | temperature avg/min/max, °C × 100 |
| 8 | i16 ×3 | humidity avg/min/max, % × 100 |
| 14 | u16 ×3 | VOC Level avg/min/max |
| 20 | u16 ×3 | CO2 avg/min/max, ppm (true CO2 on Pro, eCO2 on Base) |
| 26 | u16 ×3 | eTVOC avg/min/max, ppb |

### Client sync algorithm

```
info = read Device Info
if info.newest_seq == 0xFFFF: nothing to sync
last = highest sequence cached for this device (or none)
write History Request {0x01, after_seq: last or 0xFFFF}
collect data frames until done frame
store slots keyed by (device_id, sequence)   # idempotent
anchor timestamps: newest slot = now, each older slot -5 min
```

Sequence numbers are monotonic u16 and wrap at 0xFFFE. If the device does not
find `after_seq` in its buffer (client was away longer than 7 days, or a wrap
occurred), it streams the **full** history; dedup by sequence on the client
handles overlap.

## Concurrency rules

- One history stream at a time device-wide (BLE and USB serial share this
  lock). The loser gets error/busy and retries.
- Only one BLE central may connect (NimBLE max connections = 1).
- `clear_history` is serial-only in v1 and is refused while a stream runs.

## Sizing

Full sync: 2016 slots × 32 B = 63 KB ≈ 2–5 s at typical iOS throughput.
Incremental daily sync: 288 slots ≈ 9 KB, sub-second.

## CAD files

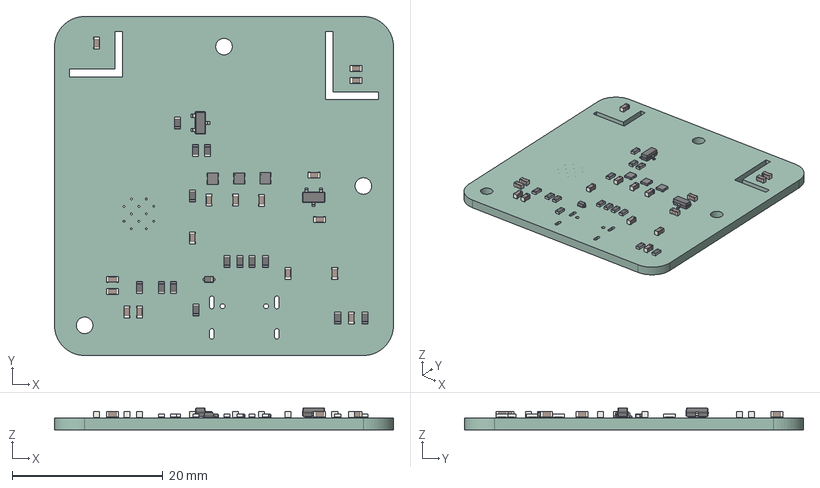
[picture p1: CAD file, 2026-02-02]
kicad/Base/AirCube.step
45.0 x 45.0 x 2.85 mm
R_0603_1608Metric x 14
C_0603_1608Metric x 16
IN-PI15_INL x 3
SOT-23 x 2
D_SOD-523
AirCube_PCB

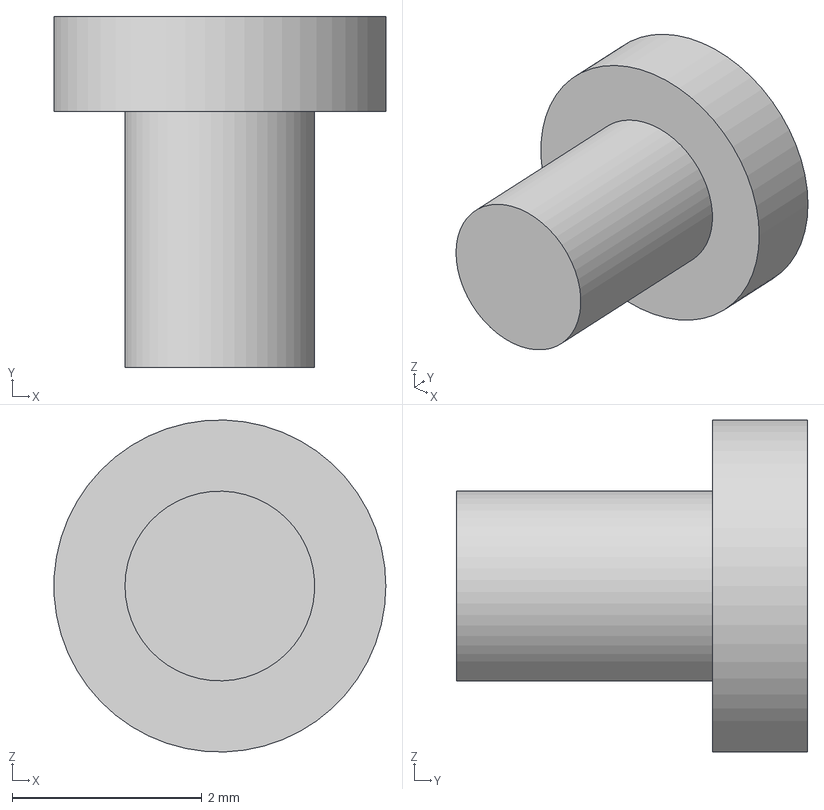
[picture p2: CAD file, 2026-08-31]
mechanical/base/STEP/AirCube_button-8-31-26.step
3.50 x 3.70 x 3.50 mm

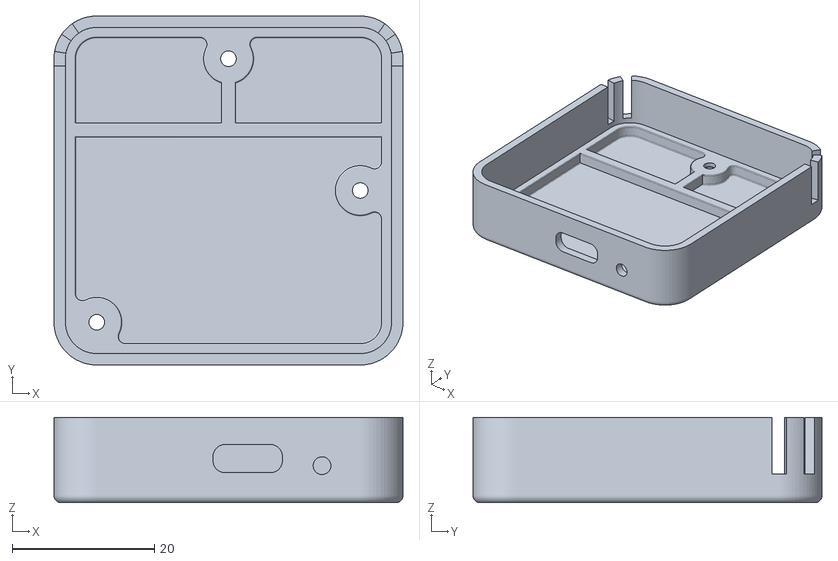
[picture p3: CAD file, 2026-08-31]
mechanical/base/STL/AirCube_bottom-8-31-26.stl
49.0 x 49.0 x 12.0

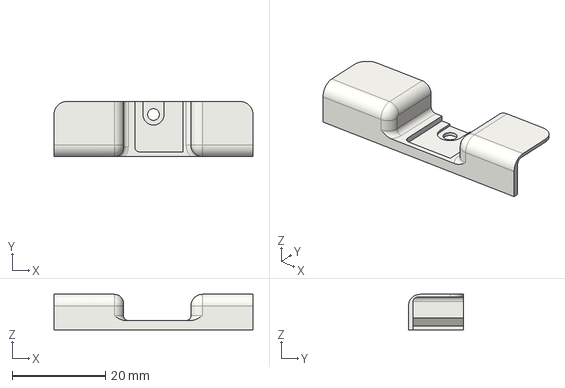
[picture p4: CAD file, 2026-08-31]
mechanical/base/STEP/AirCube_air_wall_8-31-26.step
42.6 x 11.8 x 7.60 mm

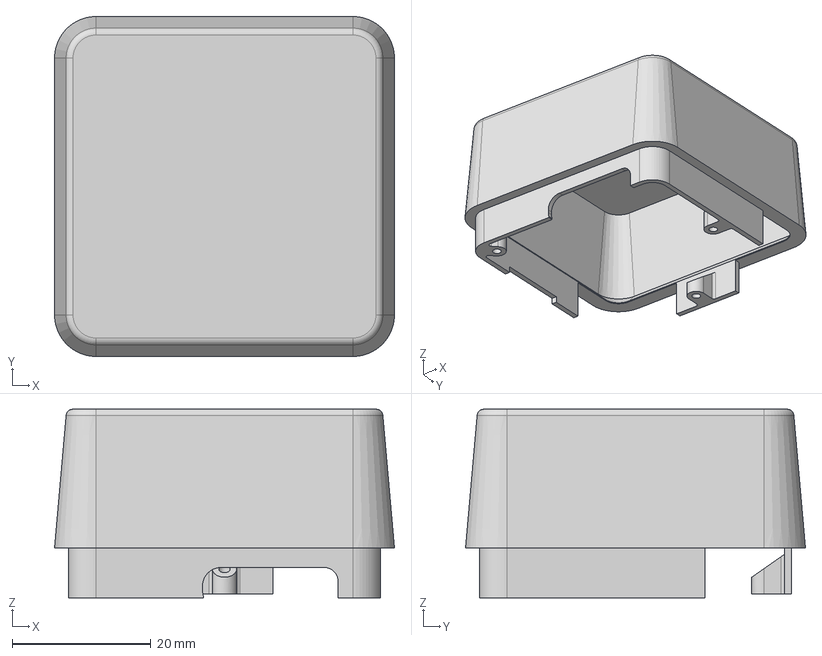
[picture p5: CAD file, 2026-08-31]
mechanical/pro/STEP/AirCube_top-8-31-26.step
49.0 x 49.0 x 27.2 mm

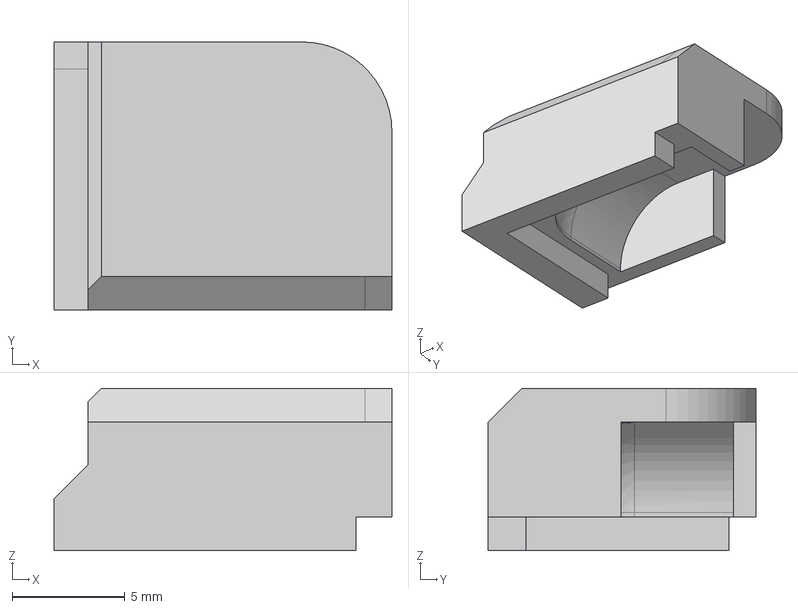
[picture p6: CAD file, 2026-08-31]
mechanical/pro/STEP/AirCube_light_wall-8-31-26.step
15.0 x 11.9 x 7.20 mm

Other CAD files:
mechanical/base/STL/AirCube_button_7-15-26-514.stl
mechanical/pro/STL/AirCube_air_wall_7-14-26-1149.stl
mechanical/base/STL/AirCube_air_wall_7-14-26-1149.stl
mechanical/pro/STL/AirCube_top-7-16-26-716.stl
mechanical/base/STEP/AirCube bottom_prod_12-11.step
mechanical/base/STL/AirCube_top-7-16-26-716.stl
mechanical/pro/STL/AirCube_button_7-15-26-514.stl
mechanical/pro/STEP/AirCube bottom_prod_12-11.step
mechanical/pro/STL/AirCube_light_wall-7-10-26-1034.stl

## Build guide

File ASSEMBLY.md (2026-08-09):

# Assembling Your AirCube

This guide walks through putting an AirCube together from printed parts and a populated PCB -- **Base** first, then **Pro**. Each model takes about ten minutes with a single screwdriver.

You'll need a populated AirCube PCB. If you don't have one, grab the [AirCube Populated PCB](https://stuckatprototype.com/products/aircube-populated-pcb) or build one from the KiCad files in [kicad/](kicad).

> Already assembled? Head back to **[Getting Started](README.md#getting-started)**.

---

## What You Need

| Item | Notes |
|---|---|
| **3x M2 x 5 mm screws** | Self-tapping, for plastic. Longer screws work too -- they just bottom out deeper. |
| **Small Phillips screwdriver** | PH0 or similar. Hand-driven, no power tools. |
| **Populated AirCube PCB** | Base or Pro. |
| **All printed parts for your model** | See below. |

### Printed parts

**Base** -- files in [mechanical/base](mechanical/base):

- `AirCube bottom_prod_12-11.step` -- bottom shell, holds the PCB
- `AirCube top 20mm PROD.step` -- top shell
- `AirCube air wall 11-7-43.3mf` -- air wall, separates the sensor from the rest of the cube

**Pro** -- files in [mechanical/pro](mechanical/pro):

- `AirCube bottom_prod_12-11.step` -- bottom shell, holds the PCB
- `AirCube_top-7-16-26-716.stl` -- top shell
- `AirCube_air_wall_7-14-26-1149.stl` -- air wall
- `AirCube_light_wall-7-10-26-1034.stl` -- light wall, shapes the LED glow
- `AirCube_button_7-15-26-514.stl` -- button cap

Print everything before you start. A missing air wall means taking the whole cube apart again.

---

## Base Assembly

### 1. Gather your screws

Three **M2 x 5 mm** self-tapping screws. Longer screws are fine.

### 2. Print all the parts

Bottom, top, and air wall -- all three on the bench before you begin.

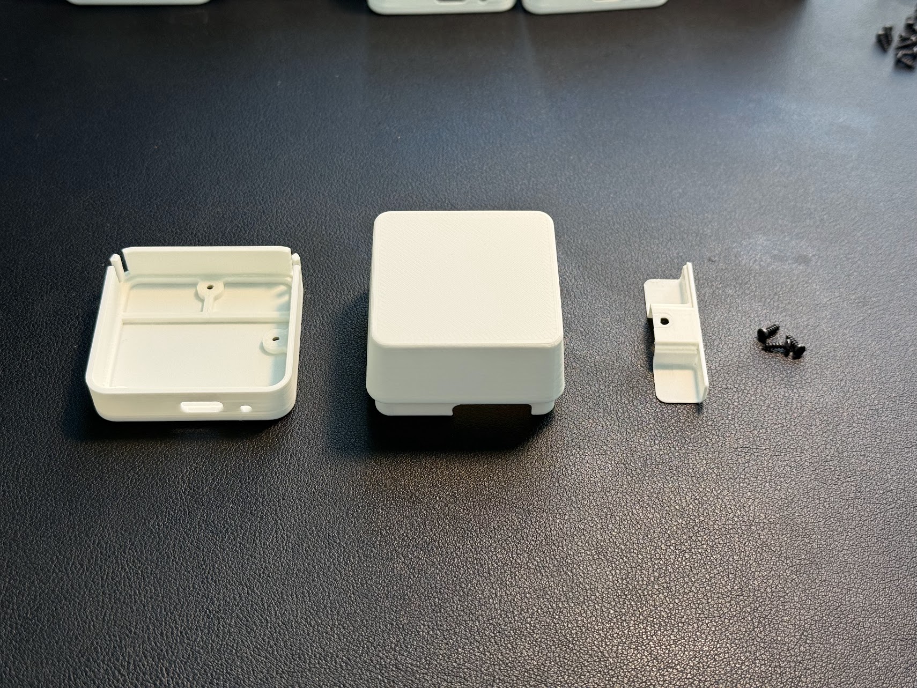
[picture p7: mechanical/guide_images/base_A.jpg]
Base printed parts and screws laid out


### 3. Drop in the PCB, USB-C end first

Angle the board so the USB-C connector slides into its opening in the bottom shell, then lower the rest of the board flat into the pocket.

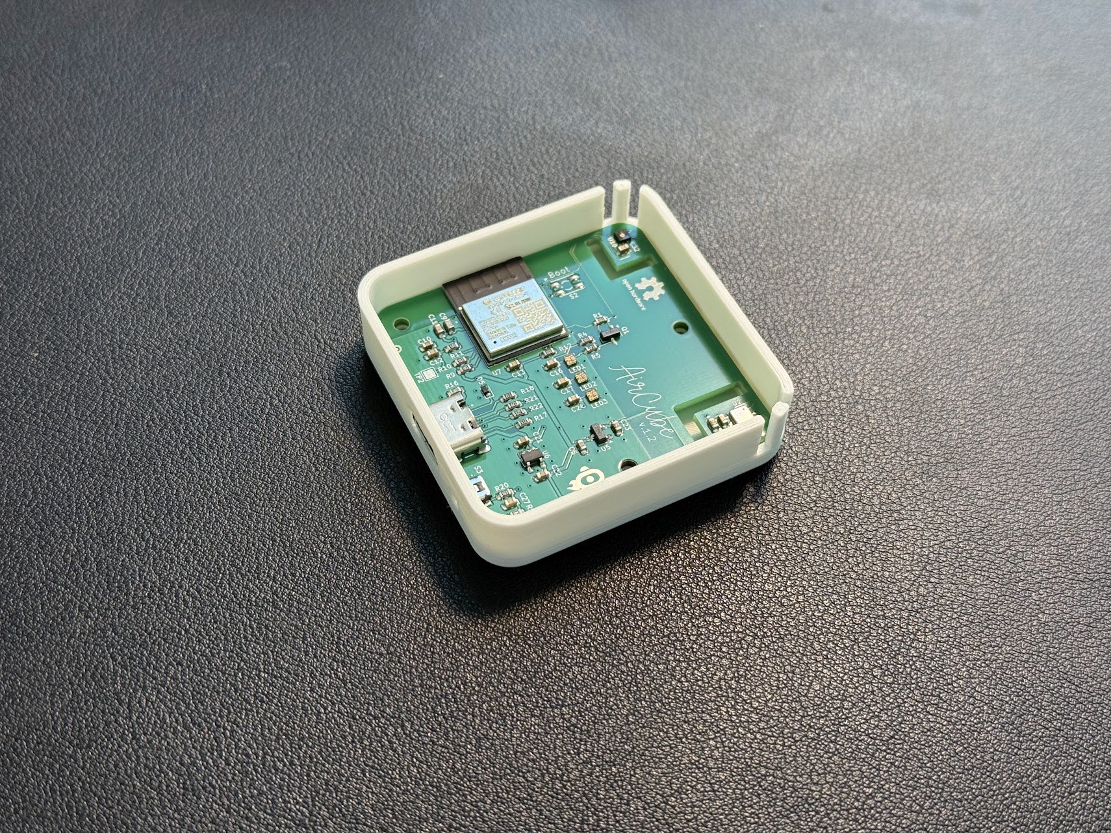
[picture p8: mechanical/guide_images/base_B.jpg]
PCB seated in the bottom shell with the USB-C port through its opening


### 4. Fit the front screw only

The bottom shell has three screw holes. Drive only the one nearest the front edge for now -- it holds the PCB down and sets up the alignment for the air wall.

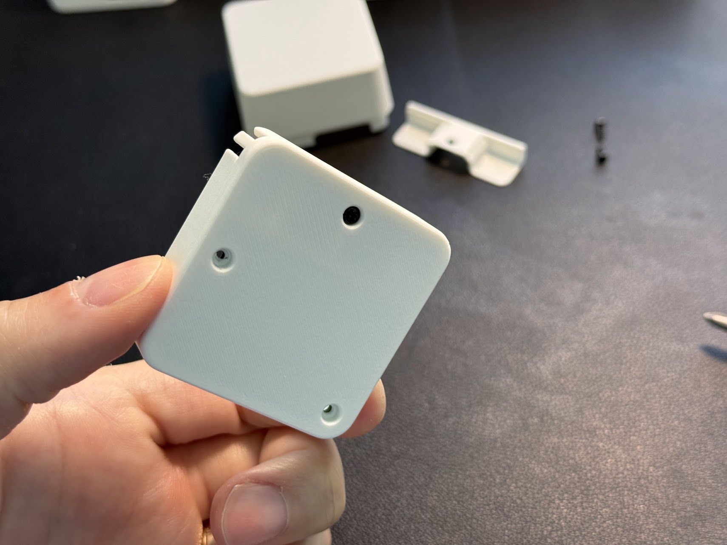
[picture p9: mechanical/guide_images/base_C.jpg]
Underside of the bottom shell showing the three screw holes


Leave the other two holes empty until the top is on.

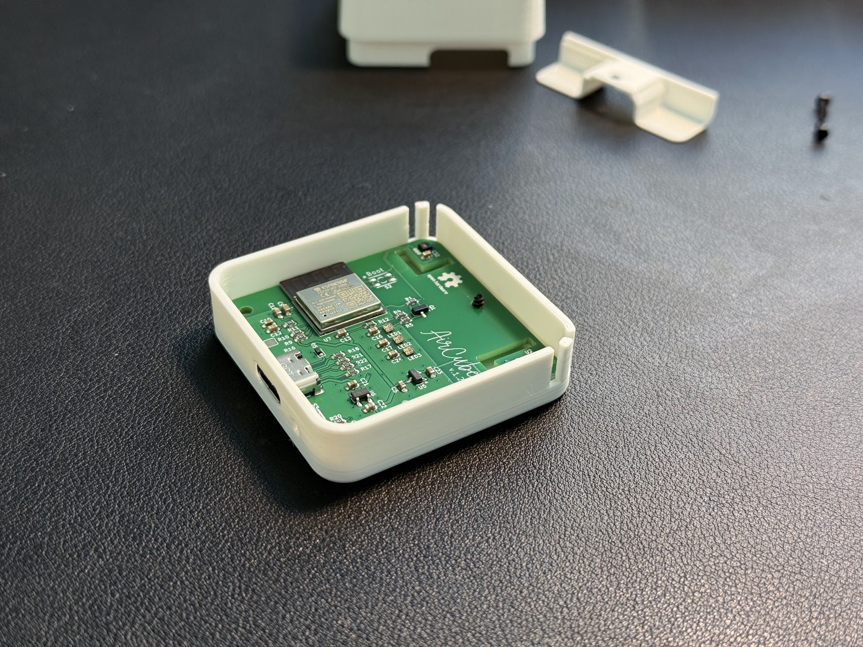
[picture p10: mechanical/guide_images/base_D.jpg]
Front screw driven, air wall standing by


### 5. Install the air wall

Drop the air wall into the cutout as pictured. It should sit flat against the PCB with no gap along the side wall.

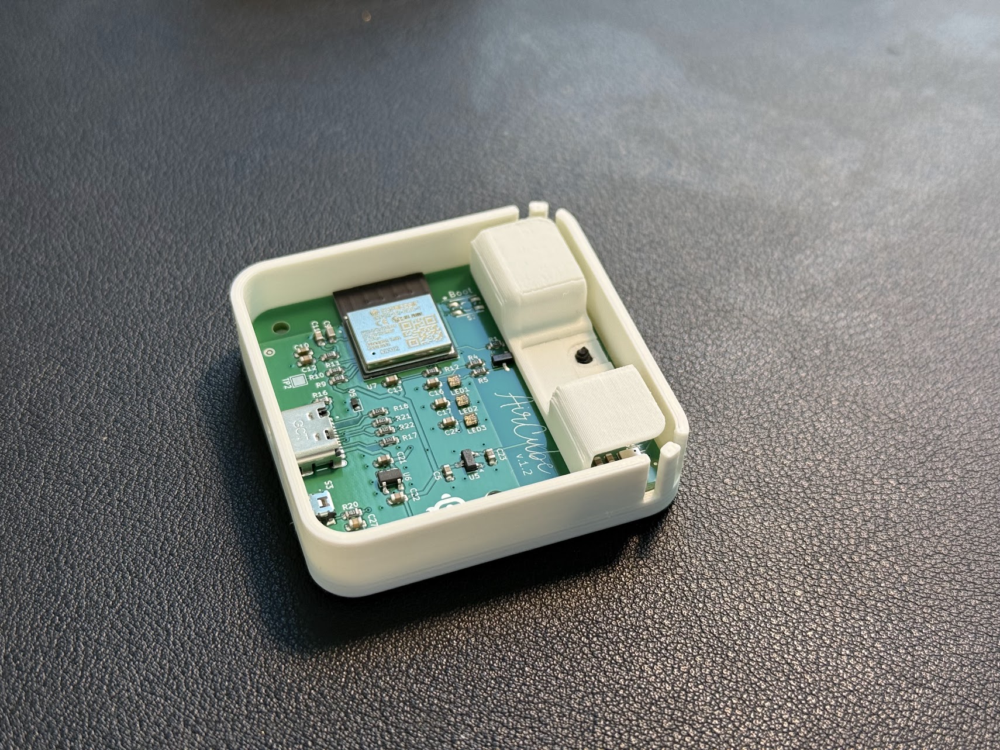
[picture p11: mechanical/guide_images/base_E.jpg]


### 6. Install the top

Lower the top onto the bottom. Line it up so the USB-C opening at the back stays fully clear -- if the port is pinched or partly covered, lift the top and reseat it.

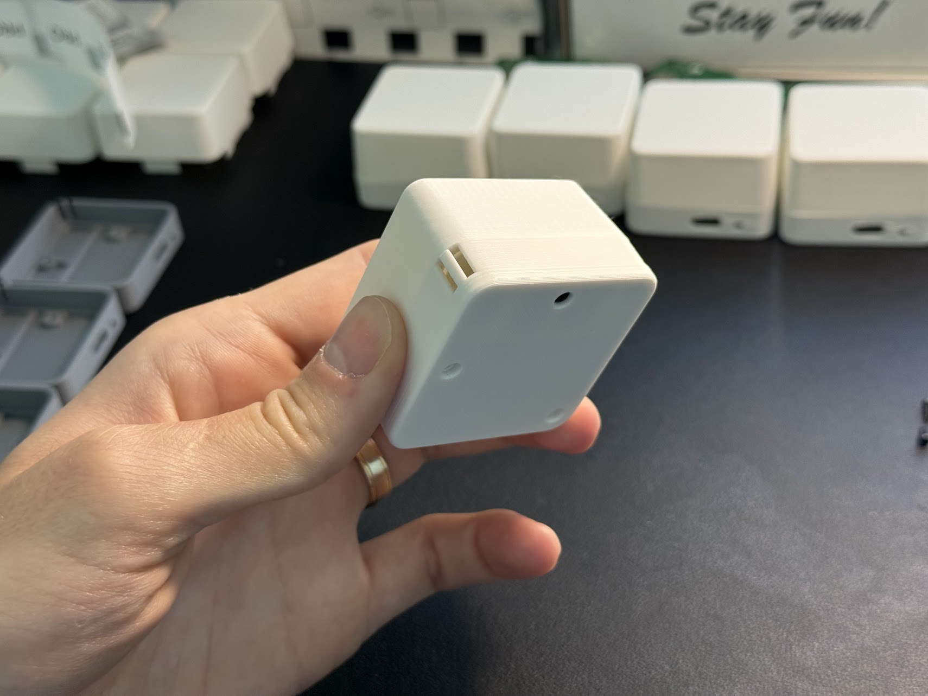
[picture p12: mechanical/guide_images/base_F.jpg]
Top installed with the USB-C opening clear and the screw holes accessible


### 7. Secure the first screw

Drive the front screw home. **Snug, not tight** -- these are self-tapping screws in plastic and it's easy to strip the thread.

### 8. Install the other two screws

Same treatment for the remaining two holes. Done.

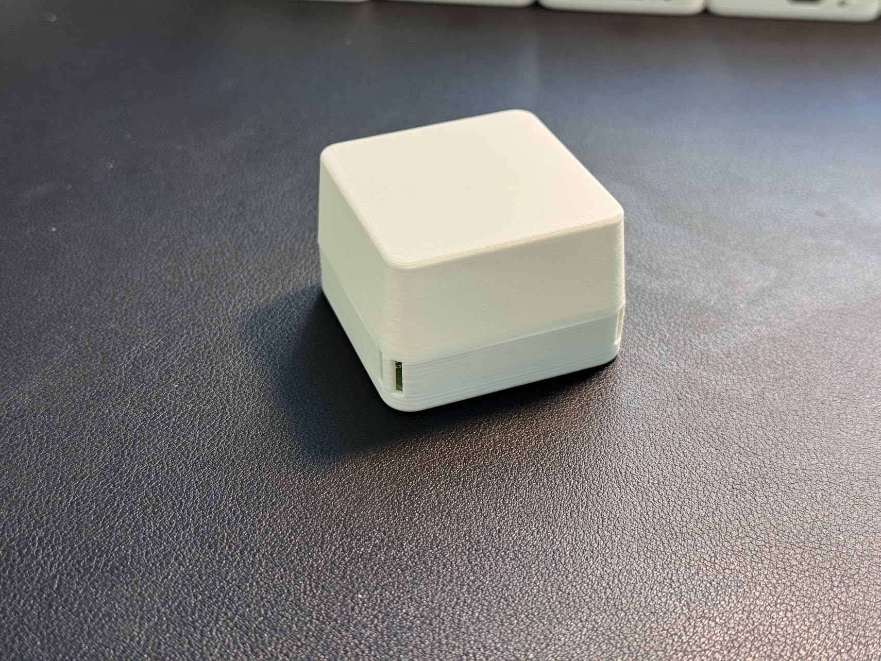
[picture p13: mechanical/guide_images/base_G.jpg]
Finished Base AirCube


---

## Pro Assembly

Pro adds two parts to the Base sequence: a button cap and a light wall.

### 1. Gather your screws

Three **M2 x 5 mm** self-tapping screws. Longer screws are fine.

### 2. Print all the parts

Bottom, top, air wall, light wall, and button cap.

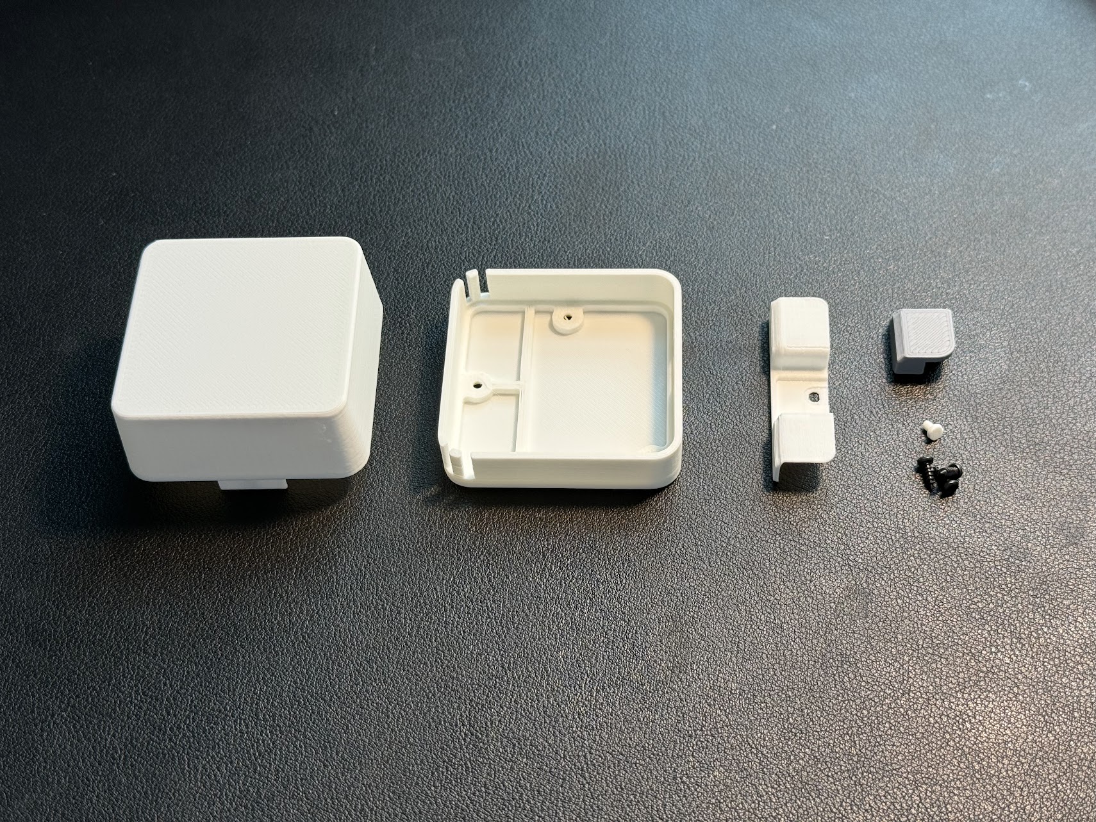
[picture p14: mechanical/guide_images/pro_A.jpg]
Pro printed parts, button cap and screws laid out


### 3. Put the button into the enclosure

Drop the button cap into its slot in the bottom shell from the inside. It goes in before the PCB -- the board is what holds it captive.

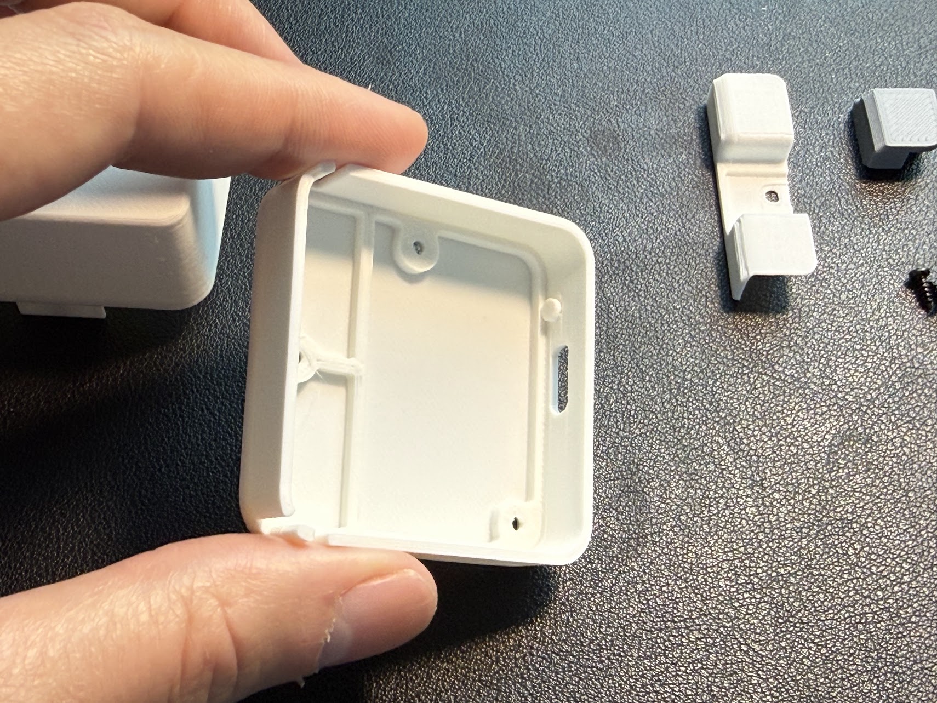
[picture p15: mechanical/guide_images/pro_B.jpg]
Bottom shell interior with the button slot


### 4. Drop in the PCB, USB-C end first

Angle the board so the USB-C connector slides into its opening, then lower it flat. Check the button cap is still seated and moves freely against the switch.

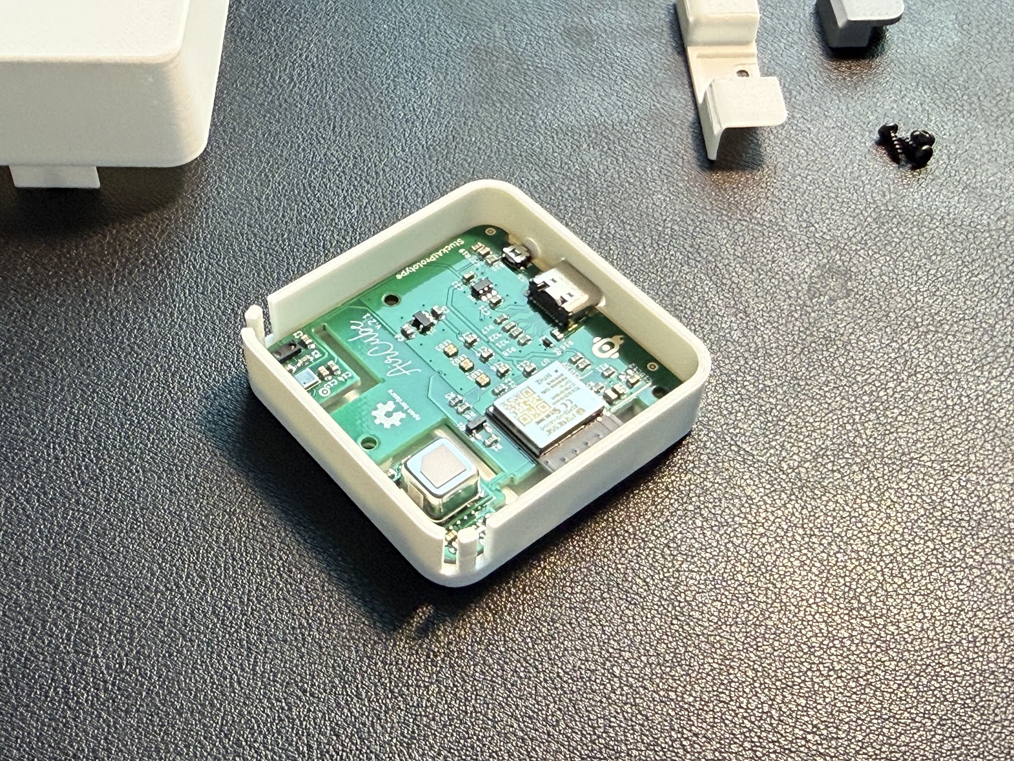
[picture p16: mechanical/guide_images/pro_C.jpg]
PCB seated in the bottom shell, button cap captured


### 5. Fit the front screw only

Drive only the screw nearest the front edge. It holds the PCB down and sets up the alignment for the air wall.

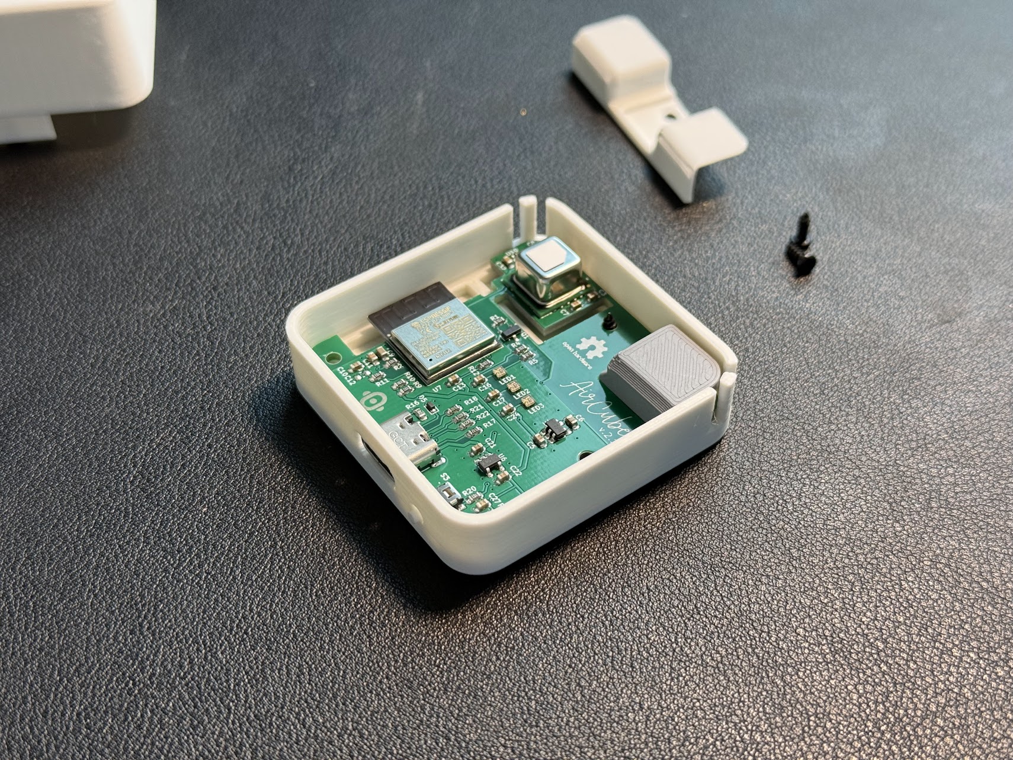
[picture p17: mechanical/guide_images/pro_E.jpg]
Front screw driven, remaining holes empty


### 6. Install the light wall

Slide the light wall into its pocket along the side wall, as pictured.

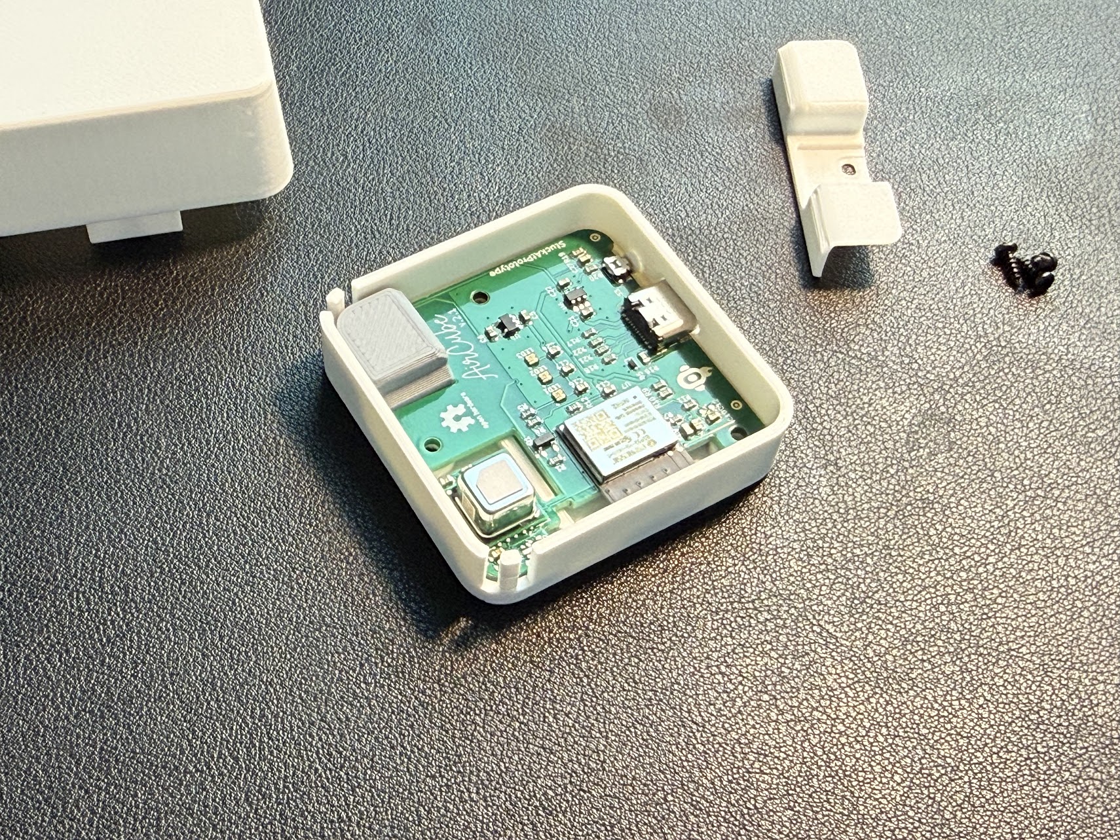
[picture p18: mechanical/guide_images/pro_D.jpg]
Light wall seated in its pocket along the side wall


### 7. Install the air wall

Drop the air wall into the cutout as pictured. It should sit flat with no gap along the side wall.

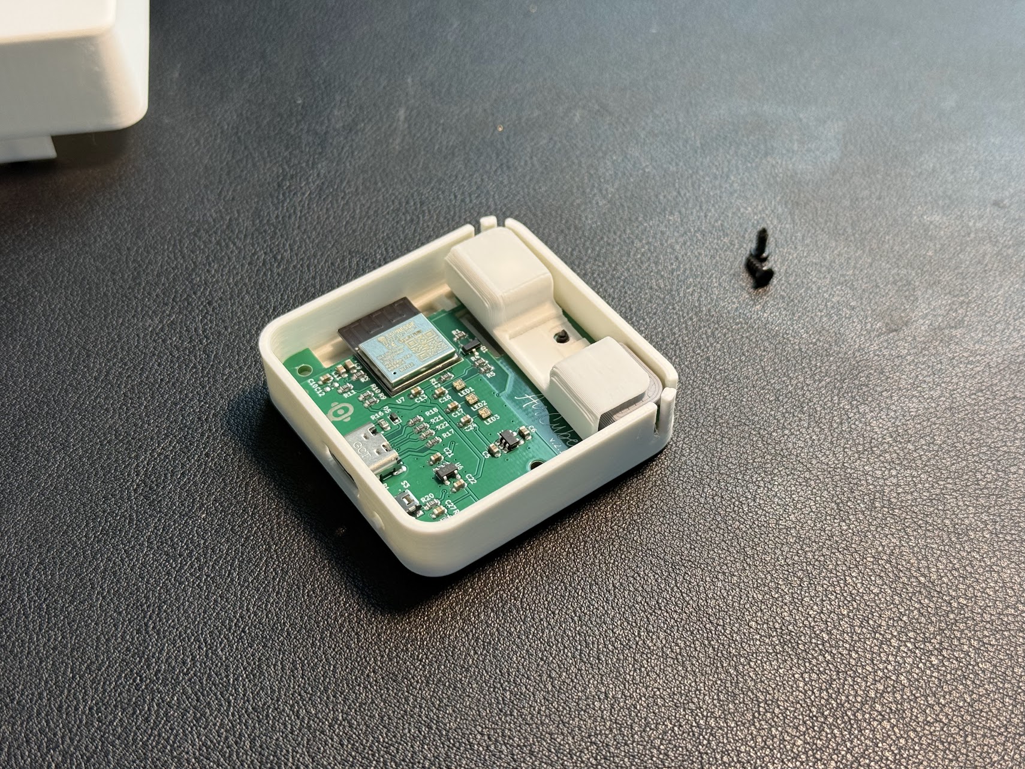
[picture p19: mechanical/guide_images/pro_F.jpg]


### 8. Install the top

Lower the top on, lined up so the USB-C opening at the back stays fully clear.

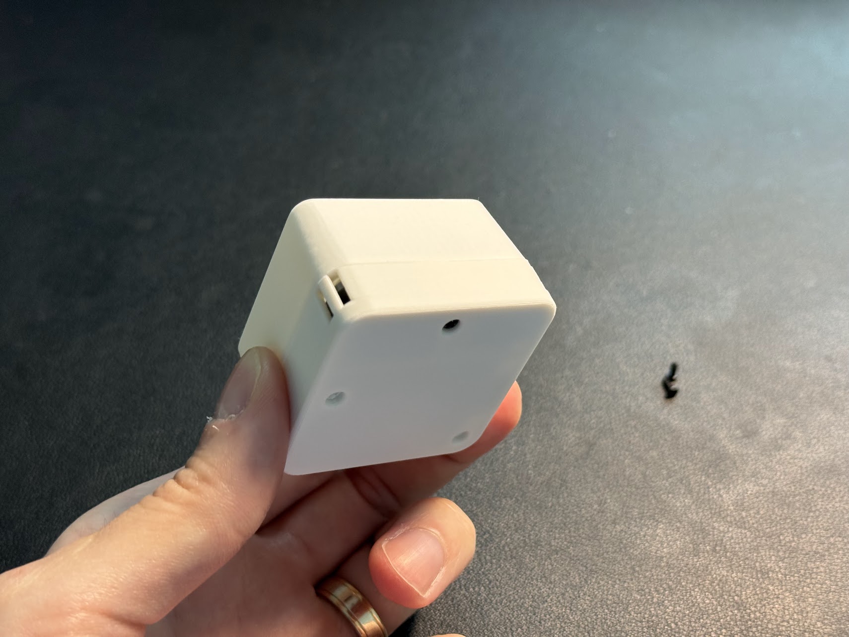
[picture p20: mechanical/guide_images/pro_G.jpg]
Top installed with the USB-C opening clear and the three screw holes accessible


### 9. Secure the first screw

Drive the front screw home. **Snug, not tight** -- self-tapping screws strip plastic threads easily.

### 10. Install the other two screws

Same treatment for the remaining two holes. Done.

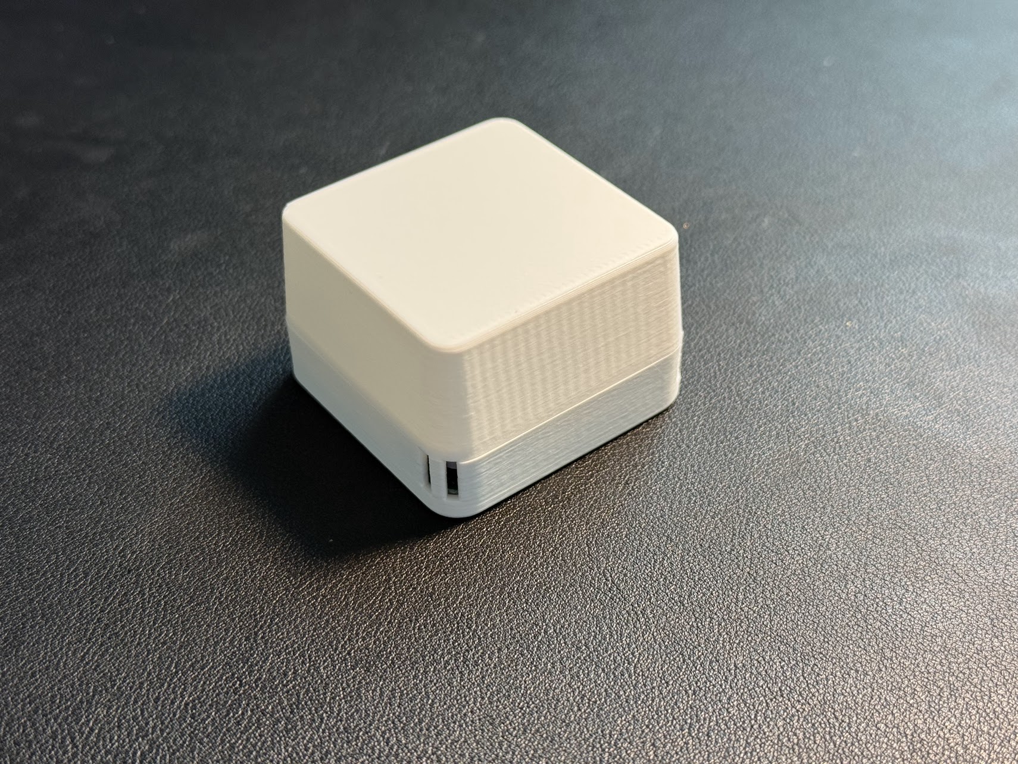
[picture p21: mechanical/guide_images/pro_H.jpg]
Finished Pro AirCube


---

## Tips and Troubleshooting

**Don't overtighten.** Every screw here is a self-tapping screw biting into printed plastic. Stop as soon as it feels snug -- another quarter turn is how you strip the hole.

**Check the USB-C opening before you drive any screws.** With the top resting in place, look down the back face. The port should be fully exposed. Clamping a misaligned top down with screws can crack the shell.

**Air wall won't sit flush?** Back the front screw out a turn or two, reseat the air wall, then retighten. The front screw sets PCB alignment, so a board that's sitting slightly proud leaves the wall standing off.

**Button feels stuck (Pro)?** Take the top off and check the cap is square in its slot. It should have a little free travel and click against the switch on the board.

**Stripped a screw hole?** A slightly longer M2 screw usually bites into fresh plastic deeper down.

---

## Next Steps

| | |
|---|---|
| [Getting Started](README.md#getting-started) | Power it up and read the LED |
| [Firmware Update Guide](FIRMWARE_UPDATE.md) | Flash the latest firmware from your browser |
| [Home Assistant Guide](HOME_ASSISTANT.md) | ZHA and Zigbee2MQTT setup |
| [Contributing Guide](CONTRIBUTING.md) | Build from source, hardware and firmware architecture |

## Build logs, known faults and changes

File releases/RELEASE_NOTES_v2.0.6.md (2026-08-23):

# AirCube firmware v2.0.6

This release makes a Pro whose CO2 channel has died say so, instead of reporting
"CO2 UNAVAILABLE" indefinitely with nothing to diagnose.

## What changed

- Counted CO2 failures separately from read failures. A frame that carries good
  temperature and humidity but a rejected CO2 word used to reset the shared
  failure counter, so a sensor that had lost only its CO2 channel never reached
  the recovery path and never reported a fault.
- After five such frames in a row (about 2.5 minutes at the low-power cadence),
  the cube now runs the SCD41's built-in self test once and logs the result,
  then falls back to the existing stop/reinit recovery. The self test is the
  only on-device check that separates an internal sensor malfunction from a
  supply that cannot hold up under the sensor's measurement peaks.
- Added `co2_fails` and `self_test` to `get_sensor_health`, so a unit in the
  field can be triaged over serial without reproducing the fault first.
- Recovered a sensor that has stopped measuring entirely. A stopped SCD41 still
  answers the bus and still reports "not ready", so no failure counter moved and
  the cube reported nothing at all, indefinitely, without logging an error. Three
  missed frames now trigger the same stop/reinit recovery. This state was
  observed once after a firmware flash, where the warm-resume path attached to a
  sensor that was no longer running.

Nothing changes on a healthy unit: the new path only runs after repeated frames
that carry valid temperature and humidity but no CO2 measurement, which a
working sensor does not produce.

## Flashing

The asset is a merged image — bootloader, partition table, and application in
one file, written at offset `0x0`.

| | |
|---|---|
| File | `AirCube_firmware_v2.0.6.bin` |
| Size | 959,472 bytes |
| SHA-256 | `34DFFC024D58FE4295AD0389292CA8E4A2171EC9F954CD23B3D388E217D009EC` |
| Target | ESP32-H2, 2 MB flash |

```
esptool --chip esp32h2 write-flash 0x0 AirCube_firmware_v2.0.6.bin
```

Or in AirCube Web: Flash → Local .bin, offset **0x0**.

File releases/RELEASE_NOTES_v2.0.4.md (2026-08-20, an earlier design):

# AirCube firmware v2.0.4

This release keeps the LED display stable through brief Zigbee radio recovery.

## What changed

- Removed the green LED blink when Zigbee reconnects after a parent link failure.
- Preserved the current air-quality color, brightness, hue, and auto-dim state
  across warm MCU restarts.
- Resumed the Pro model's running SCD41 measurement cycle after a warm restart
  instead of restarting the sensor.
- Kept the existing blue pairing-mode indication unchanged.

## Flashing

`AirCube_firmware_v2.0.4.bin` is a merged ESP32-H2 image. Flash it at offset
`0x0`.

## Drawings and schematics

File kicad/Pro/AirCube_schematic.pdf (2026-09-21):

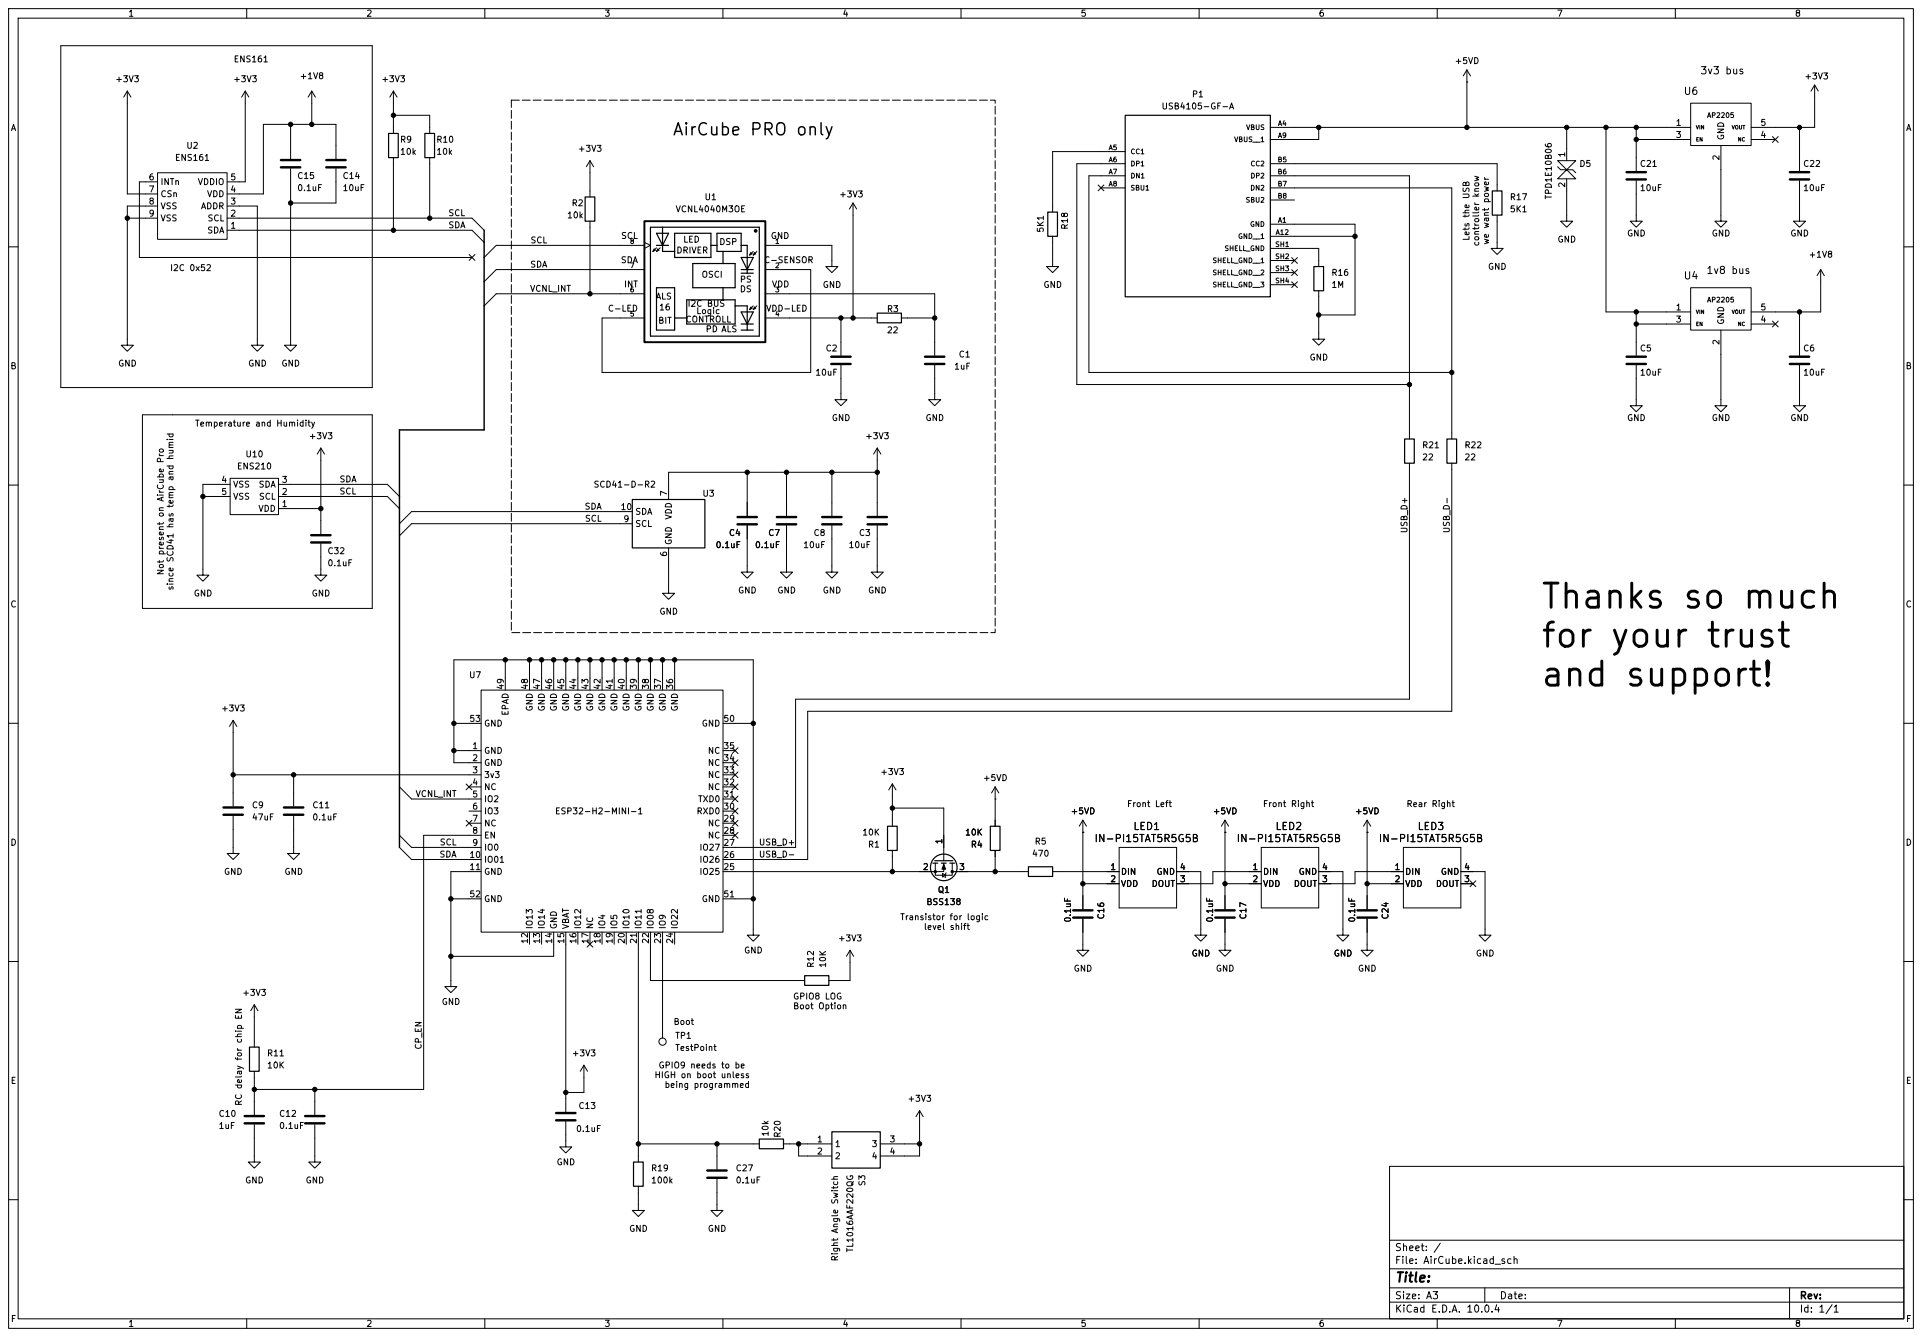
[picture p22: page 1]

AirCube PRO only

LED BIT ALS
I2C BUS OSCI Logic PD DRIVER

VSS 8

Size: A3 | Rev: | F Date:
KiCad E.D.A. 10.0.4 | Id: 1/1

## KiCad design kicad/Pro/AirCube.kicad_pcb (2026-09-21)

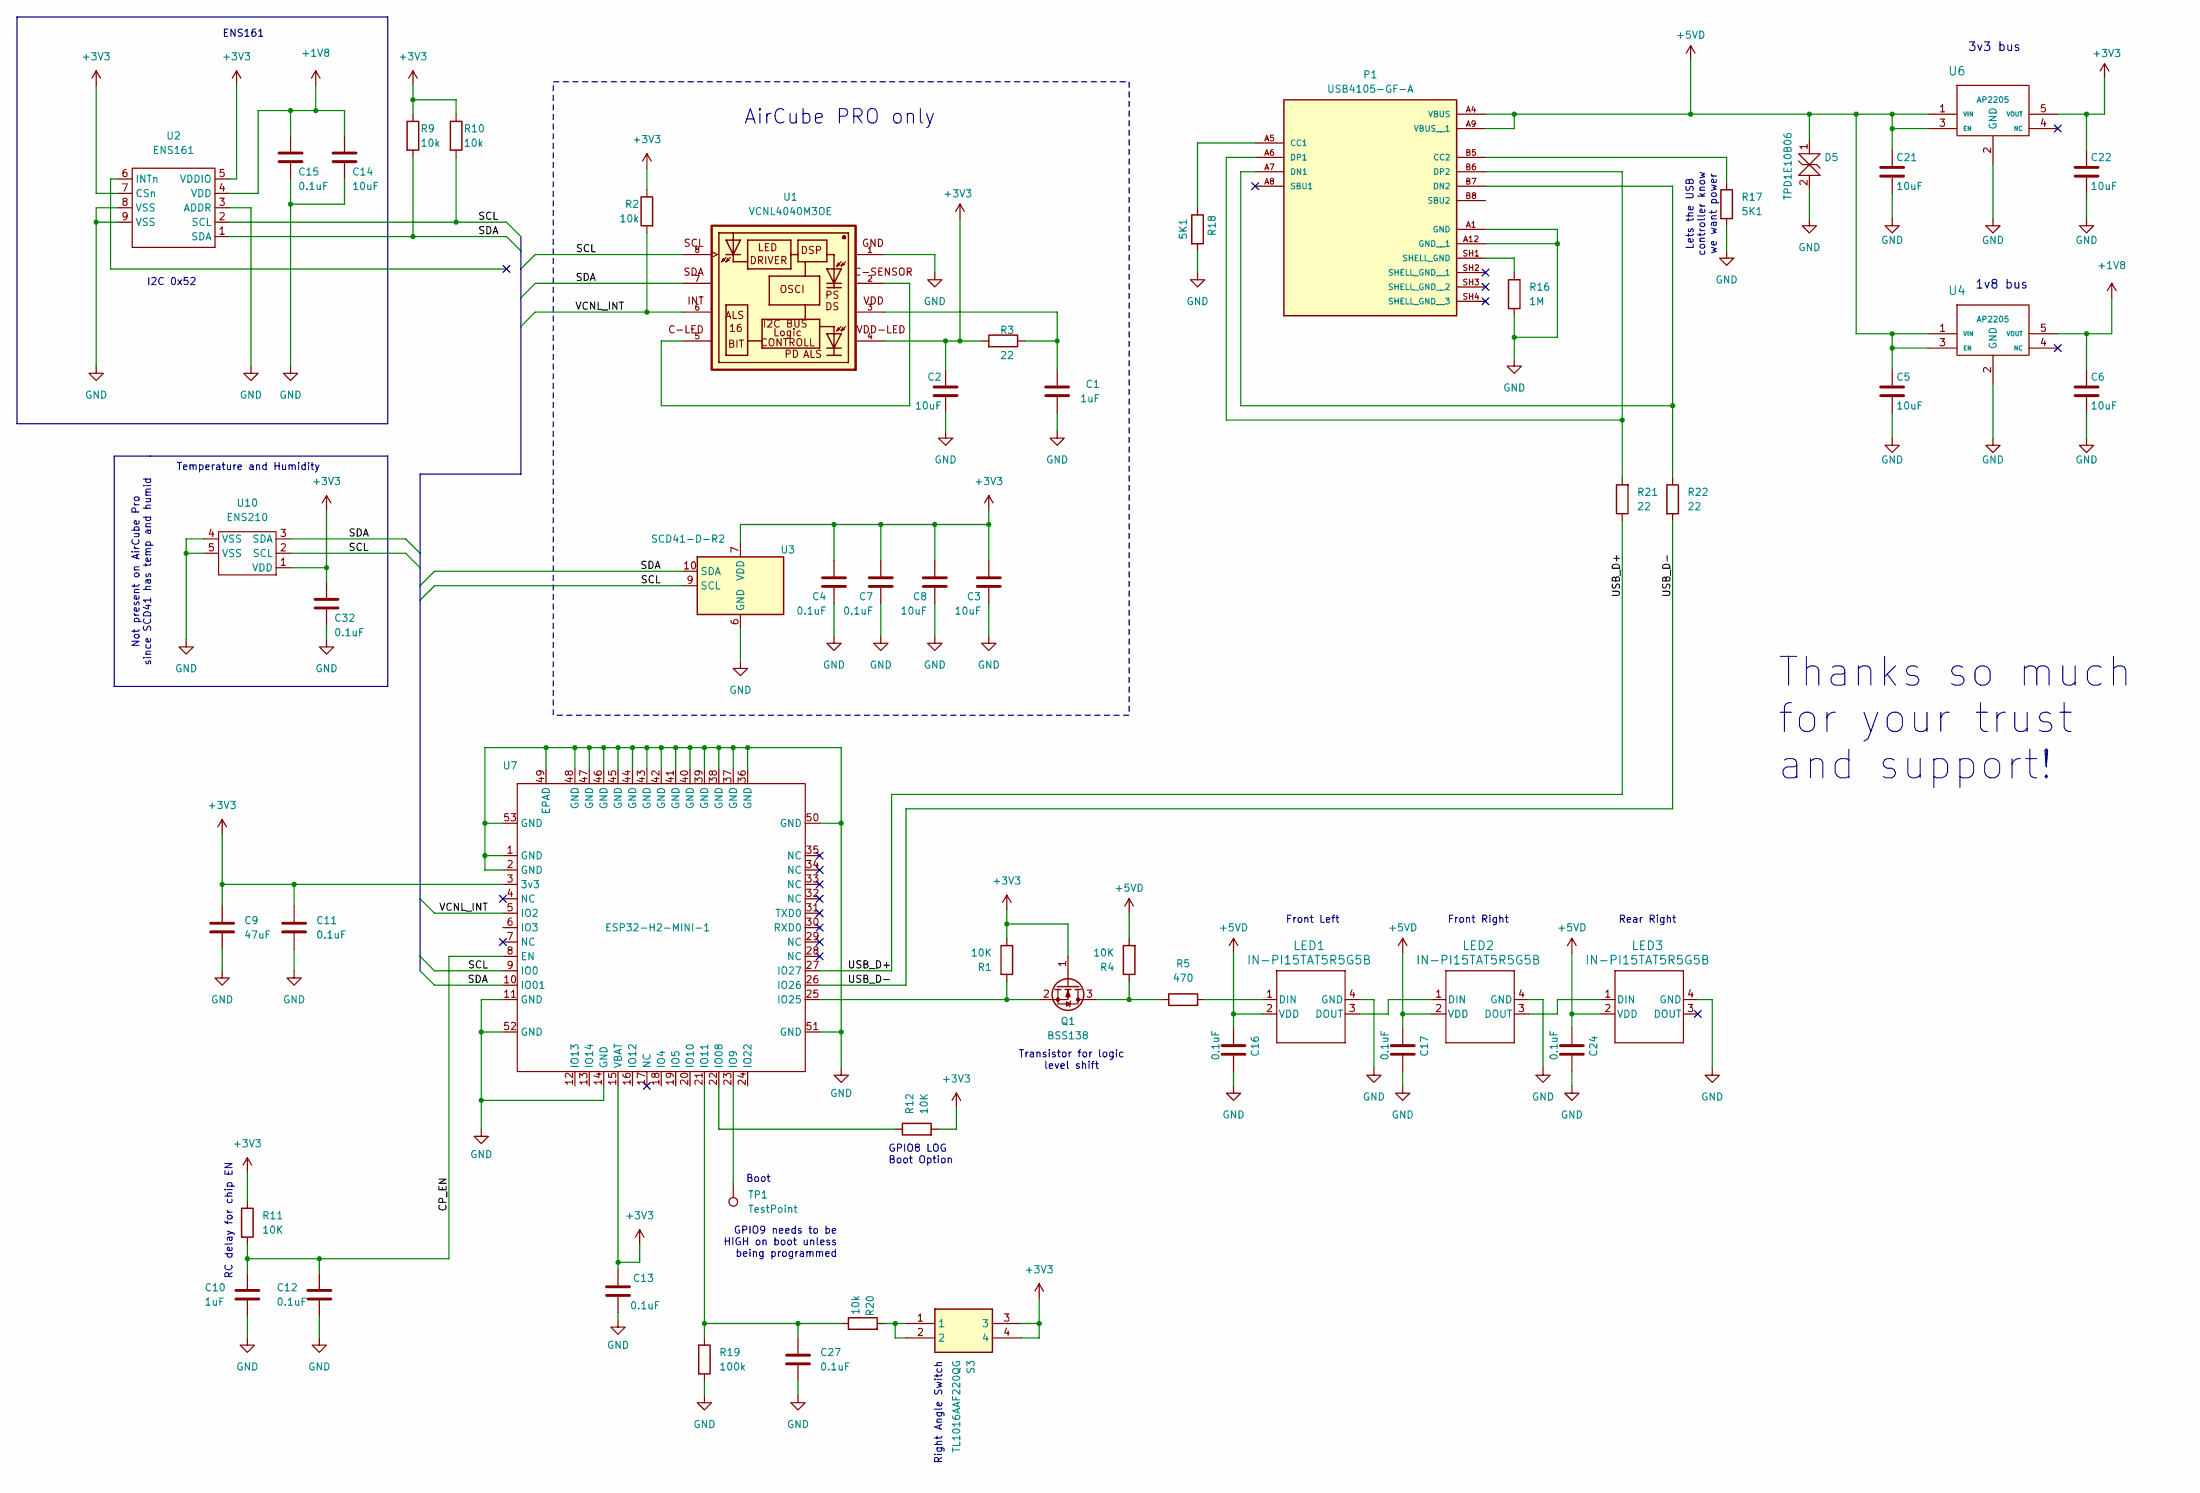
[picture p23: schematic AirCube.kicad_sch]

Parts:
C1, C10: 1uF; C_0603_1608Metric
C2, C3, C5, C6, C8, C14, C21, C22: 10uF; C_0603_1608Metric
C4, C7, C11, C12, C13, C15, C16, C17, C24, C27, C32: 0.1uF; C_0603_1608Metric
C9: 47uF; C_0603_1608Metric
D5: TPD1E10B06; D_SOD-523
LED1, LED2, LED3: IN-PI15TAT5R5G5B; IN-PI15_INL
P1: USB4105-GF-A; GCT_USB4105-GF-A; PARTREV B4
Q1: BSS138; SOT-23
R1, R4, R11, R12: 10K; R_0603_1608Metric
R2, R9, R10, R20: 10k; R_0603_1608Metric
R3, R21, R22: 22; R_0603_1608Metric
R5: 470; R_0603_1608Metric
R16: 1M; R_0603_1608Metric
R17, R18: 5K1; R_0603_1608Metric
R19: 100k; R_0603_1608Metric
S3: TL1016AAF220QG; Mouser Part Number 612-TL1016AAF220QG
TP1: TestPoint; TestPoint_Pad_D1.0mm
U1: VCNL4040M3OE; VISHAY_VCNL4040_4X2X1.1
U2: ENS161
U3: SCD41-D-R2; Sensirion_SCD4x-1EP_10.1x10.1mm_P1.25mm_EP4.8x4.8mm
U4, U6: AP2205; AP2204
U7: ESP32-H2-MINI-1; MODULE_ESP32-H2-MINI-1-H2
U10: ENS210

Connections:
+1V8: C6.1, C14.1, C15.1, U2.4 (VDD), U4.5 (VOUT)
+3V3: C2.1, C3.1, C4.1, C7.1, C8.1, C9.1, C11.1, C13.1, C22.1, C32.1, Q1.1 (G), R1.2, R2.1, R3.2, R9.1, R10.1, R11.1, R12.2, S3.3, S3.4, U1.4, U2.5 (VDDIO), U2.7 (CSn), U3.7 (VDD), U3.19 (VDD), U6.5 (VOUT), U7.3 (3v3), U7.15 (VBAT), U10.1 (VDD)
+5VD: C5.1, C16.1, C17.1, C21.1, C24.1, D5.1, LED1.2 (VDD), LED2.2 (VDD), LED3.2 (VDD), P1.A4 (VBUS), P1.A9 (VBUS__1), R4.2, U4.1 (VIN), U4.3 (EN), U6.1 (VIN), U6.3 (EN)
/CP_EN: C10.1, C12.1, R11.2, U7.8 (EN)
/SCL: R10.2, U1.8, U2.2 (SCL), U3.9 (SCL), U7.9 (IO0), U10.2 (SCL)
/SDA: R9.2, U1.7, U2.1 (SDA), U3.10 (SDA), U7.10 (IO01), U10.3 (SDA)
/USB_D+: R21.1, U7.27 (IO27)
/USB_D-: R22.2, U7.26 (IO26)
/VCNL_INT: R2.2, U1.6, U7.5 (IO2)
GND: C1.2, C2.2, C3.2, C4.2, C5.2, C6.2, C7.2, C8.2, C9.2, C10.2, C11.2, C12.2, C13.2, C14.2, C15.2, C16.2, C17.2, C21.2, C22.2, C24.2, C27.2, C32.2, D5.2, LED1.4 (GND), LED2.4 (GND), LED3.4 (GND), P1.A1 (GND), P1.A12 (GND__1), R16.2, R17.2, R18.2, R19.2, U1.1, U2.3 (ADDR), U2.8 (VSS), U2.9 (VSS), U3.6 (GND), U3.20 (GND), U3.21 (GND), U4.2 (GND), U6.2 (GND), U7.1 (GND), U7.2 (GND), U7.11 (GND), U7.14 (GND), U7.36 (GND), U7.37 (GND), U7.38 (GND), U7.39 (GND), U7.40 (GND), U7.41 (GND), U7.42 (GND), U7.43 (GND), U7.44 (GND), U7.45 (GND), U7.46 (GND), U7.47 (GND), U7.48 (GND), U7.49 (EPAD), U7.50 (GND), U7.51 (GND), U7.52 (GND), U7.53 (GND), U10.4 (VSS), U10.5 (VSS)
unnamed: C1.1, R3.1, U1.3
unnamed: LED1.1 (DIN), R5.2
unnamed: LED1.3 (DOUT), LED2.1 (DIN)
unnamed: LED2.3 (DOUT), LED3.1 (DIN)
unnamed: P1.A5 (CC1), R18.1
unnamed: P1.B5 (CC2), R17.1
unnamed: P1.A7 (DN1), P1.B7 (DN2), R22.1
unnamed: P1.A6 (DP1), P1.B6 (DP2), R21.2
unnamed: P1.SH1 (SHELL_GND), R16.1
unnamed: Q1.3 (D), R4.1, R5.1
unnamed: Q1.2 (S), R1.1, U7.25 (IO25)
unnamed: R20.2, S3.1, S3.2
unnamed: U1.2, U1.5
unnamed: R12.1, U7.22 (IO08)
unnamed: TP1.1, U7.23 (IO9)
unnamed: C27.1, R19.1, R20.1, U7.21 (IO11)

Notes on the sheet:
Not present on AirCube Pro since SCD41 has temp and humid
Rear Right
AirCube PRO only
Transistor for logic level shift
GPIO8 LOG Boot Option
Boot
Thanks so much for your trust and support!
Right Angle Switch
Lets the USB controller know we want power
Front Right
ENS161
3v3 bus
GPIO9 needs to be HIGH on boot unless being programmed
Front Left
I2C 0x52
RC delay for chip EN
1v8 bus
Temperature and Humidity

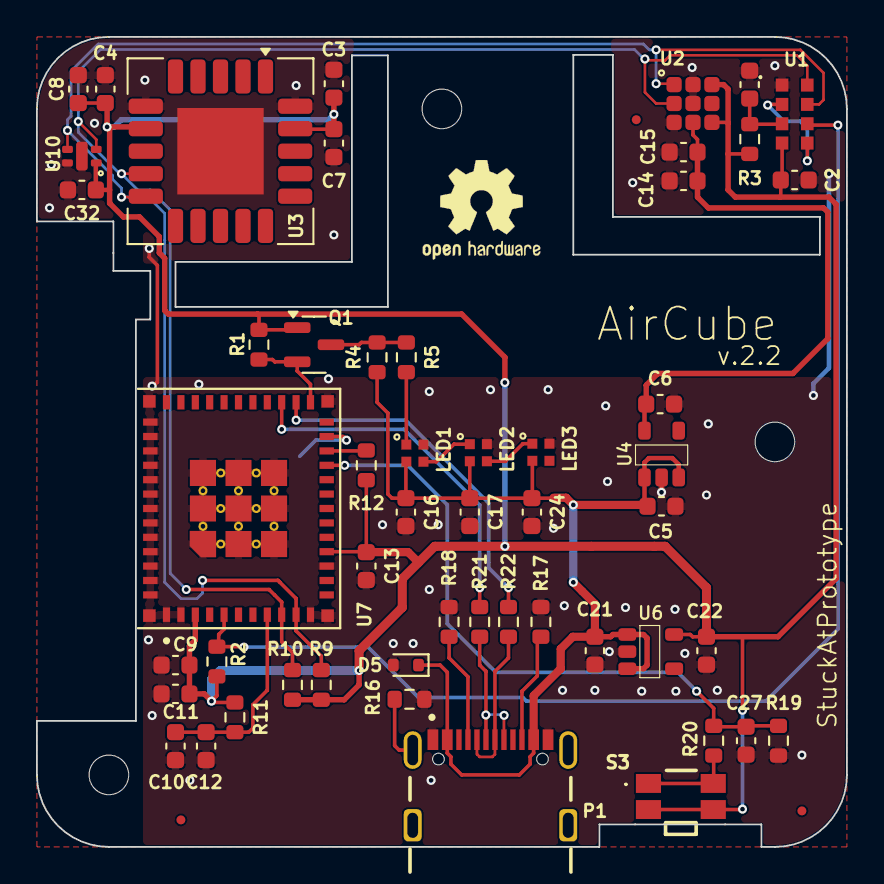
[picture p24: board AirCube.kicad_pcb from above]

Board: 2 copper layers, 45.0 x 45.0 mm, 53 parts (1 on the bottom side), 26 nets.

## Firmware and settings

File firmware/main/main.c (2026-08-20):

#include "freertos/FreeRTOS.h"
#include "freertos/task.h"
#include "freertos/semphr.h"
#include "esp_log.h"
#include "esp_pm.h"
#include "esp_task_wdt.h"
#include "nvs_flash.h"
#include "led_color_lib.h"

#include "led.h"
#include "ens210.h"
#include "ens16x_driver.h"
#include "scd41.h"
#include "vcnl4040.h"
#include "device_model.h"
#include "i2c_driver.h"
#include "serial_protocol.h"
#include "button.h"
#include "auto_dim.h"
#include "history.h"
#include "zigbee.h"
#include "radio_mode.h"
#include "ble_gatt.h"
#include "restart_state.h"

static const char *TAG = "main";

#define SENSOR_TASK_STACK_SIZE 6144
#define SENSOR_TASK_PRIORITY 5
#define COMMAND_TASK_STACK_SIZE 4096
#define COMMAND_TASK_PRIORITY 4

// Configurable sensor readout period (default 1000ms)
static uint32_t sensor_readout_period_ms = 1000;
static SemaphoreHandle_t readout_period_mutex = NULL;

// LED color mapping: continuous green->red gradient from whichever of
// VOC Level / CO2 Level is currently worse (Pro); VOC Level only (Base).
#define AQI_MIN 0
#define AQI_MAX 200
#define AQI_GREEN_THRESHOLD 10  // Values 0-10 are pure green

#define HUE_GREEN  21845  // 120 deg - pure green

// Shared 0-500 severity checkpoints. Both the VOC and CO2 threshold tables
// below map their raw units onto these same bands, so the two resulting
// levels are directly comparable (see co2_calculate()/aqi_calculate()).
static const uint16_t AQI_LEVEL_BANDS[6] = {
    0,    // Level 0
    15,   // Level 1 - Excellent / Good edge
    50,   // Level 2 - Good / Moderate edge
    100,  // Level 3 - Moderate / Poor edge
    200,  // Level 4 - Poor / Unhealthy edge
    500   // Level 5 - Unhealthy cap
};

// VOC Level values at each TVOC band edge (matches published VOC table):
//   0-65 ppb      -> VOC Level 0-15   (Excellent)
//   65-220 ppb    -> VOC Level 15-50  (Good)
//   220-650 ppb   -> VOC Level 50-100 (Moderate)
//   650-2200 ppb  -> VOC Level 100-200 (Poor)
//   2200-5500 ppb -> VOC Level 200-500 (Unhealthy)
// Driven by TVOC alone; eCO2 is reported separately as raw ppm.
static const int AQI_TVOC_THRESHOLDS_PPB[5] = { 65, 220, 650, 2200, 5500 };

// CO2 ppm bands -> CO2 Level (EN 16798-1-style indoor-air categories),
// Pro hardware (SCD41) only:
//   800-1000 ppm   -> CO2 Level 15-50   (Cat I/II edge)
//   1000-1500 ppm  -> CO2 Level 50-100  (Cat II/III edge)
//   1500-2000 ppm  -> CO2 Level 100-200 (Cat III/IV edge)
//   2000-5000 ppm  -> CO2 Level 200-500 (unhealthy -> OSHA 8h TWA cap)
static const int AQI_CO2_THRESHOLDS_PPM[5] = { 800, 1000, 1500, 2000, 5000 };

// Canonical VOC Level (TVOC-derived) and CO2 Level (SCD41-derived, Pro only)
// for LED color mapping. The LED loop picks whichever is worse each tick.
static int current_voc_level = 0;
static int current_co2_level = 0;  // Pro only; 0 (best) until SCD41 has data

// Static variables for smooth LED color transitions
static float current_hue = 21845.0f;  // Current hue value (21845 = green, 0 = red) - using float for smooth transitions
static uint16_t target_hue = 21845;   // Target hue value we want to transition to
#define TRANSITION_SPEED 0.02f  // Transition speed per update (0.0 to 1.0, higher = faster)
// With 20ms update interval and 0.02 speed, full transition takes ~1 second (50 steps)

// Getter and setter for sensor readout period (for serial_protocol.c)
uint32_t get_sensor_readout_period_ms(void)
{
    uint32_t period = 1000;
    if (readout_period_mutex != NULL) {
        if (xSemaphoreTake(readout_period_mutex, portMAX_DELAY) == pdTRUE) {
            period = sensor_readout_period_ms;
            xSemaphoreGive(readout_period_mutex);
        }
    }
    return period;
}

void set_sensor_readout_period_ms(uint32_t period)
{
    if (readout_period_mutex != NULL) {
        if (xSemaphoreTake(readout_period_mutex, portMAX_DELAY) == pdTRUE) {
            sensor_readout_period_ms = period;
            xSemaphoreGive(readout_period_mutex);
        }
    }
}

/**
 * @brief Map VOC Level value to hue
 * 
 * Maps canonical VOC Level (TVOC-derived, 0-500) to LED hue:
 * - VOC Level 0-10: pure green (no color change)
 * - VOC Level 10-200: smooth gradient from green to red
 * - VOC Level 200+: full red (handled by caller)
 * 
 * @param aqi VOC Level value
 * @return 16-bit hue value (21845 = green, 0 = red)
 */
static uint16_t aqi_to_hue(int aqi)
{
    // Clamp VOC Level to valid range
    if (aqi < AQI_MIN) aqi = AQI_MIN;
    if (aqi > AQI_MAX) aqi = AQI_MAX;
    
    // Values 0-10 are pure green
    if (aqi <= AQI_GREEN_THRESHOLD) {
        return HUE_GREEN;
    }
    
    // For values 10-200, map smoothly from green to red
    // Map VOC Level from [10, 200] to ratio [0.0, 1.0] for smooth gradient
    // When VOC Level = 10: ratio = 0.0 (green)
    // When VOC Level = 200: ratio = 1.0 (red)
    float ratio = (float)(aqi - AQI_GREEN_THRESHOLD) / (float)(AQI_MAX - AQI_GREEN_THRESHOLD);
    
    // Linear interpolation from green to red
    // ratio = 0.0 -> hue = HUE_GREEN (green)
    // ratio = 1.0 -> hue = 0 (red)
    uint16_t hue = HUE_GREEN - (uint16_t)(ratio * HUE_GREEN);
    
    return hue;
}

/**
 * @brief Map a raw sensor value to a continuous band position 0.0..5.0
 *
 * Generic across sources: interpolates `value` against a 5-point threshold
 * table (ppb for VOC, ppm for CO2) whose edges correspond to band 1..5.
 */
static float value_to_level_pos(int value, const int thresholds[5])
{
    if (value <= 0) {
        return 0.0f;
    }
    if (value >= thresholds[4]) {
        return 5.0f;
    }
    if (value < thresholds[0]) {
        return (float)value / (float)thresholds[0];
    }
    for (int i = 0; i < 4; i++) {
        if (value < thresholds[i + 1]) {
            float span = (float)(thresholds[i + 1] - thresholds[i]);
            float frac = (float)(value - thresholds[i]) / span;
            return (float)(i + 1) + frac;
        }
    }
    return 5.0f;
}

/**
 * @brief Map a raw sensor value to a 0-500 severity level via a threshold table.
 *
 * Shared by aqi_calculate() (VOC, TVOC ppb) and co2_calculate() (CO2 ppm) so
 * both land on the same 0-500 scale and are directly comparable.
 *
 * @param value Raw sensor value (ppb or ppm)
 * @param thresholds 5-point band-edge table, in the same units as `value`
 * @param bands 6-point Level table (see AQI_LEVEL_BANDS)
 * @return Severity level in [0, 500]
 */
static uint16_t level_from_thresholds(int value, const int thresholds[5], const uint16_t bands[6])
{
    float pos = value_to_level_pos(value, thresholds);
    if (pos <= 0.0f) {
        return bands[0];
    }
    if (pos >= 5.0f) {
        return bands[5];
    }

    int low = (int)pos;
    if (low > 4) {
        low = 4;
    }
    float frac = pos - (float)low;

    int32_t a_low  = (int32_t)bands[low];
    int32_t a_high = (int32_t)bands[low + 1];
    int32_t level = a_low + (int32_t)((a_high - a_low) * frac);

    if (level < 0) {
        level = 0;
    }
    if (level > 500) {
        level = 500;
    }
    return (uint16_t)level;
}

/**
 * @brief Compute the canonical AirCube VOC Level from TVOC.
 *
 * Maps TVOC ppb to VOC Level 0-500 using fixed indoor-air bands (see AQI_LEVEL_BANDS).
 * TVOC-only; eCO2 is reported separately. LED color follows this VOC Level via
 * aqi_to_hue() (green at 0-10, gradient to red at 200+).
 *
 * @param etvoc Equivalent TVOC in ppb
 * @return VOC Level value in [0, 500]
 */
static uint16_t aqi_calculate(int etvoc)
{
    return level_from_thresholds(etvoc, AQI_TVOC_THRESHOLDS_PPB, AQI_LEVEL_BANDS);
}

/**
 * @brief Compute the AirCube CO2 Level from true (SCD41) CO2 ppm. Pro only.
 *
 * Maps CO2 ppm to CO2 Level 0-500 using EN 16798-1-style bands (see
 * AQI_CO2_THRESHOLDS_PPM), on the same 0-500 scale as VOC Level so the LED
 * loop can directly compare the two and show whichever is worse.
 *
 * @param co2_ppm True CO2 in ppm
 * @return CO2 Level value in [0, 500]
 */
static uint16_t co2_calculate(int co2_ppm)
{
    return level_from_thresholds(co2_ppm, AQI_CO2_THRESHOLDS_PPM, AQI_LEVEL_BANDS);
}

/**
 * @brief Startup animation - sweeps from green to red and back to green
 * 
 * This function displays a 3-second animation that smoothly transitions
 * from green to red and back to green when the device starts up.
 * Uses time-based animation to ensure accurate timing.
 */
static void startup_animation(void) {
    const uint32_t ANIMATION_DURATION_MS = 3000;  // 3 seconds total
    const uint32_t UPDATE_INTERVAL_MS = 10;  // Update every 10ms for smooth animation
    
    // Get start time in ticks
    TickType_t start_ticks = xTaskGetTickCount();
    TickType_t duration_ticks = pdMS_TO_TICKS(ANIMATION_DURATION_MS);
    
    while (1) {
        // Calculate elapsed time
        TickType_t current_ticks = xTaskGetTickCount();
        TickType_t elapsed_ticks = current_ticks - start_ticks;
        
        // Check if animation is complete
        if (elapsed_ticks >= duration_ticks) {
            break;
        }
        
        // Calculate progress from 0.0 to 1.0 based on elapsed time
        float progress = (float)elapsed_ticks / (float)duration_ticks;
        
        uint16_t hue;
        if (progress <= 0.5f) {
            // First half: green to red (0.0 to 0.5)
            float ratio = progress * 2.0f;  // 0.0 to 1.0
            hue = HUE_GREEN - (uint16_t)(ratio * HUE_GREEN);
        } else {
            // Second half: red back to green (0.5 to 1.0)
            float ratio = (progress - 0.5f) * 2.0f;  // 0.0 to 1.0
            hue = (uint16_t)(ratio * HUE_GREEN);
        }
        
        // Get color from hue (intensity is applied by LED task)
        uint32_t color = get_color_from_hue(hue);
        led_set_color(color);
        
        // Delay until next update
        vTaskDelay(pdMS_TO_TICKS(UPDATE_INTERVAL_MS));
    }
    
    // Ensure we end on green
    uint32_t final_color = get_color_from_hue(HUE_GREEN);
    led_set_color(final_color);
}

/**
 * @brief Build ENS16X temperature/humidity compensation bytes from floats.
 *
 * The ENS16X TEMP_IN/RH_IN registers (written by ens16x_write_ens210_data())
 * use the same encoding as the ENS210 raw output: temperature in 1/64 K and
 * relative humidity in 1/512 %, each a little-endian uint16. On Pro hardware
 * the ENS210 is absent, so we synthesize these bytes from the SCD41 readings.
 */
static void compose_ens16x_compensation(float temp_c, float humidity,
                                        uint8_t t[2], uint8_t h[2])
{
    uint16_t t_raw = (uint16_t)((temp_c + 273.15f) * 64.0f);
    uint16_t h_raw = (uint16_t)(humidity * 512.0f);
    t[0] = (uint8_t)(t_raw & 0xFF);
    t[1] = (uint8_t)(t_raw >> 8);
    h[0] = (uint8_t)(h_raw & 0xFF);
    h[1] = (uint8_t)(h_raw >> 8);
}

// Command processing task
void command_task(void *pvParameters)
{
    ESP_LOGI(TAG, "Command task started");
    
    while (1) {
        // Process incoming commands
        serial_process_commands();
        
        // Small delay to prevent CPU spinning
        vTaskDelay(10 / portTICK_PERIOD_MS);
    }
}
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
void app_main(void)
{
    restart_state_init();
    restart_visual_state_t restored_visual_state = {0};
    bool restored_visual = restart_state_get_visual(&restored_visual_state);
    if (restored_visual) {
        current_hue = restored_visual_state.hue;
        target_hue = (uint16_t)restored_visual_state.hue;
        current_voc_level = restored_visual_state.voc_level;
        current_co2_level = restored_visual_state.co2_level;
    }

    ESP_LOGI(TAG, "AirCube");

    ESP_LOGI(TAG, "LED color: continuous green->red from canonical VOC Level (TVOC-derived)");

    // Configure power management
    // ESP32-H2 valid max frequencies: 96, 64, or 48 MHz. Min = XTAL = 32 MHz.
    esp_pm_config_t pm_config = {
        .max_freq_mhz = 48,            // Maximum CPU frequency (MHz)
        .min_freq_mhz = 32,            // Minimum CPU frequency (XTAL, MHz)
        .light_sleep_enable = false     // Automatic light sleep when idle
    };
    
    esp_err_t ret = esp_pm_configure(&pm_config);
    if (ret != ESP_OK) {
        ESP_LOGE(TAG, "Failed to configure power management: %s", esp_err_to_name(ret));
    } else {
        ESP_LOGI(TAG, "Power management configured with automatic light sleep enabled");
    }

    // Initialize NVS (Non-Volatile Storage) for saving settings
    ret = nvs_flash_init();
    if (ret == ESP_ERR_NVS_NO_FREE_PAGES || ret == ESP_ERR_NVS_NEW_VERSION_FOUND) {
        // NVS partition was truncated and needs to be erased
        // Retry nvs_flash_init
        ESP_ERROR_CHECK(nvs_flash_erase());
        ret = nvs_flash_init();
    }
    ESP_ERROR_CHECK(ret);
    ESP_LOGI(TAG, "NVS initialized");

    // Initialize I2C driver (must be done before initializing sensors)
    if (i2c_driver_init() != ESP_OK) {
        ESP_LOGE(TAG, "Failed to initialize I2C driver");
        return;
    }

    // Create mutex for readout period
    readout_period_mutex = xSemaphoreCreateMutex();
    if (readout_period_mutex == NULL) {
        ESP_LOGE(TAG, "Failed to create readout period mutex");
        return;
    }
    
    // Initialize serial protocol
    serial_protocol_init();
    
    // Initialize LED control system
    led_init();

    if (restored_visual) {
        led_restore_state(restored_visual_state.color, restored_visual_state.intensity);
        ESP_LOGI(TAG, "Restored LED color and brightness after warm restart");
    } else {
        // Set initial LED color to green on an actual power-up.
        uint32_t start_color = get_color_from_hue(HUE_GREEN);
        led_set_color(start_color);
    }

    
    // // Play startup animation (3 second sweep from green to red and back)
    // ESP_LOGI(TAG, "Playing startup animation");
    // startup_animation();
    
    // Initialize history module (sensor data logging to flash)
    esp_err_t hist_ret = history_init();
    if (hist_ret != ESP_OK) {
        ESP_LOGW(TAG, "History init failed: %s (continuing without history)", esp_err_to_name(hist_ret));
    }
    
    // Initialize button for brightness control
    button_init();
    
    // Resolve Base vs Pro before any sensor init: the model is latched in NVS
    // and decides which sensors this board is expected to have. A missing
    // sensor is reported as a fault by device_model and does not change the
    // model. This also gates temp/RH source selection and Pro-only Zigbee
    // clusters.
    aircube_model_resolve();

    // ENS16X air quality is fitted on both models.
    ens16x_init();
    ESP_LOGI(TAG, "ENS16X initialized");

    if (aircube_model_is_pro()) {
        scd41_init(restart_state_should_resume_scd41());
        restart_state_set_scd41_running(scd41_is_present());
        ESP_LOGI(TAG, "SCD41 %s", scd41_is_present() ? "present" : "not present");
        vcnl4040_init();
        ESP_LOGI(TAG, "VCNL4040 %s", vcnl4040_is_present() ? "present" : "not present");
    } else {
        restart_state_set_scd41_running(false);
        ens210_init();
        ESP_LOGI(TAG, "ENS210 %s", ens210_is_present() ? "present" : "not present");
    }

    // Apply configured brightness through auto-dim (Pro) or pass-through (Base).
    if (restored_visual) {
        auto_dim_restore_night_state(restored_visual_state.auto_dim_night);
    }
    auto_dim_init();
    
    // BLE-first radio mode: exactly one radio stack runs per boot (BLE+Zigbee
    // coexistence hung the PHY on the H2). Default is BLE with a connectable
    // GATT service; Zigbee only when commissioned or a pairing was requested.
    // Transitions happen via NVS flags + reboot (see radio_mode.h).
    radio_mode_init();
    if (radio_mode_is_zigbee_mode()) {
        // Zigbee End Device (steers immediately if a pairing was requested)
        zigbee_init();
    } else {
        // Connectable GATT service + BTHome advertising
        ble_gatt_init();
        // A warm radio recovery must not replace the restored air-quality color.
        if (!restored_visual) {
            // Mode cue: two quick blue blinks when entering BLE mode
            for (int i = 0; i < 2; i++) {
                led_set_color(LED_COLOR_BLUE);
                vTaskDelay(pdMS_TO_TICKS(120));
                led_set_color(LED_COLOR_OFF);
                vTaskDelay(pdMS_TO_TICKS(120));
            }
        }
    }
    
    // Create command processing task
    xTaskCreate(command_task, "command_task", COMMAND_TASK_STACK_SIZE, NULL, 
                COMMAND_TASK_PRIORITY, NULL);
    ESP_LOGI(TAG, "Command task created");
    
    // Create sensor reading task
    xTaskCreate(sensor_task, "sensor_task", SENSOR_TASK_STACK_SIZE, NULL, 
                SENSOR_TASK_PRIORITY, NULL);
    ESP_LOGI(TAG, "Sensor task created");

    // Main loop for LED color based on VOC Level (with pairing override)
    while (1) {
        vTaskDelay(pdMS_TO_TICKS(20));  // Update LED every 20ms for smooth transitions

        // Retain the exact frame and ramped brightness continuously in RTC RAM.
        // This is zero-wear memory and makes a forced MCU restart visually seamless.
        restart_visual_state_t live_visual = {
            .color = led_get_color(),
            .intensity = led_get_intensity(),
            .hue = current_hue,
            .voc_level = (uint16_t)current_voc_level,
            .co2_level = (uint16_t)current_co2_level,
            .auto_dim_night = auto_dim_is_night(),
        };
        restart_state_update_visual(&live_visual);
        
        // ── Pairing mode: flash blue at 2 Hz ──
        if (zigbee_is_pairing()) {
            uint32_t tick_ms = xTaskGetTickCount() * portTICK_PERIOD_MS;
            bool on = ((tick_ms / 250) % 2) == 0;
            led_set_color(on ? LED_COLOR_BLUE : LED_COLOR_OFF);
            continue;   // Skip normal VOC Level color while pairing
        }
        
        // ── Normal mode: continuous green->red from whichever is worse ──
        // VOC and CO2 are scored independently on the same 0-500 scale; the
        // worse of the two (never a blend of both) drives the color. CO2 is
        // only considered on Pro hardware (current_co2_level stays 0 on Base).
        int display_level = current_voc_level;
        bool co2_is_worse = false;
        if (aircube_model_is_pro() && current_co2_level > display_level) {
            display_level = current_co2_level;
            co2_is_worse = true;
        }

        static bool was_co2_worse = false;
        if (co2_is_worse != was_co2_worse) {
            ESP_LOGI(TAG, "LED now driven by %s Level (VOC %d, CO2 %d)",
                     co2_is_worse ? "CO2" : "VOC", current_voc_level, current_co2_level);
            was_co2_worse = co2_is_worse;
        }

        if (display_level >= AQI_MAX) {
            target_hue = 0;  // Red for high severity
        } else {
            target_hue = aqi_to_hue(display_level);
        }
        
        // Smoothly transition current_hue towards target_hue
        float hue_diff = (float)target_hue - current_hue;
        current_hue += hue_diff * TRANSITION_SPEED;
        
        // Convert current hue to color (cast to uint16_t for color conversion)
        uint32_t color = get_color_from_hue((uint16_t)current_hue);
        
        // Update LED with the smoothly transitioning color
        led_set_color(color);
    }
}

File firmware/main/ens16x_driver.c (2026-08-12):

//
// Created by glina126 on 11/8/2023.
//

#include "ens16x_driver.h"
#include "i2c_driver.h"
#include <string.h>
#include "esp_log.h"
#include "esp_err.h"

#define ENS16X_I2C_ADDRESS 0x52

// registers
#define ENS16X_DEVICE_STATUS 0x20
#define ENS16X_OPMODE 0x10
#define ENS16X_REG_DATA_ETVOC 0x22
#define ENS16X_REG_DATA_ECO2 0x24
#define ENS16X_REG_DATA_AQI_UBA 0x21

#define ENS16X_REG_RH_IN 0x15
#define ENS16X_REG_TH_IN 0x13

enum ENS_OPMODE ens16x_op_mode = ENS_RESERVED;
enum ENS_STATUS ens16x_status = ENS_RESET;
uint8_t ens16x_new_data_available = 0;
uint8_t ens16x_new_gpr_available = 0;
int ens16x_tvoc = -1;
int ens16x_eco2 = -1;
int ens16x_aqi = -1;
int ens16x_aqi_uba = -1;


enum ENS_OPMODE ens16x_get_opmode(void);
void ens16x_set_opmode(enum ENS_OPMODE mode);

int ens16x_get_device_status(void){

    // read in ENS16x part number
    uint8_t i2c_data[1];
    memset(i2c_data, 0, 1);
    uint8_t i2c_byte_address[] = {ENS16X_DEVICE_STATUS};
    if (i2c_driver_read(ENS16X_I2C_ADDRESS, i2c_byte_address, 1, i2c_data, 1) != ESP_OK) {
        // Without a status byte we know nothing about the sensor, so say so
        // rather than decoding the zeroed buffer into a confident "OK".
        ens16x_new_data_available = 0;
        ens16x_new_gpr_available = 0;
        ens16x_status = ENS_NO_VALID_OUTPUT;
        return -1;
    }

    // bit 0 = NEWGPR
    // bit 1 = NEWDAT
    // bit 2-3 = VALIDITY FLAG (2-bit field: 0=OK, 1=WARM_UP, 2=RESERVED, 3=NO_VALID_OUTPUT)
    // bit 6 = STATER - error invalid operating mode
    // bit 7 = STATS - OPMODE is running
    ens16x_new_data_available = (i2c_data[0] & (1U << 1)) >> 1;
    ens16x_new_gpr_available = (i2c_data[0] & (1U << 0)) >> 0;
    ens16x_status = (i2c_data[0] >> 2) & 0x03;  // Extract bits 2-3 as 2-bit value

    return i2c_data[0];

}

enum ENS_OPMODE ens16x_get_opmode(void){
    uint8_t i2c_data[1];
    memset(i2c_data, 0, 1);
    uint8_t i2c_byte_address[] = {ENS16X_OPMODE};
    i2c_driver_read(ENS16X_I2C_ADDRESS, i2c_byte_address, 1, i2c_data, 1);
    return i2c_data[0];
}

void ens16x_set_opmode(enum ENS_OPMODE mode){
    uint8_t i2c_data[2];
    memset(i2c_data, 0, 2);
    i2c_data[0] = ENS16X_OPMODE;

    // transition the sensor to idle mode first
    i2c_data[1] = ENS_IDLE;
    i2c_driver_write(ENS16X_I2C_ADDRESS, i2c_data, 2);

    // transition to ENS_OPMODE
    i2c_data[1] = mode;
    i2c_driver_write(ENS16X_I2C_ADDRESS, i2c_data, 2);

    // confirm by reading
    uint8_t i2c_return_data[1];
    uint8_t reg_addr[1] = {ENS16X_OPMODE};
    i2c_driver_read(ENS16X_I2C_ADDRESS, reg_addr, 1, i2c_return_data, 1);
    ESP_LOGD("ens16x", "operational mode: %u", i2c_data[0]);
    if(i2c_return_data[0] == mode){
        ESP_LOGI("ens16x", "Mode change success");
    } else
        ESP_LOGE("ens16x", "Error changing modes");
}

int ens16x_read_etvoc(void){
    uint8_t i2c_data[2];
    memset(i2c_data, 0, 2);
    uint8_t i2c_byte_address[] = {ENS16X_REG_DATA_ETVOC};
    if (i2c_driver_read(ENS16X_I2C_ADDRESS, i2c_byte_address, 1, i2c_data, 2) != ESP_OK) {
        ESP_LOGW("ens16x", "eTVOC read failed");
        ens16x_tvoc = -1;
        return -1;
    }
    uint16_t etvoc = ((uint16_t )i2c_data[0] | (uint16_t)i2c_data[1] << 8);

    ESP_LOGD("ens16x", "ETVOC_LSB: %u, ETVOC_MSB: %u", i2c_data[0], i2c_data[1]);
    ESP_LOGI("ens16x", "etvoc: %hu", etvoc);
    ens16x_tvoc = etvoc;

    return etvoc;
}

int ens16x_read_eco2(void){
    uint8_t i2c_data[2];
    memset(i2c_data, 0, 2);
    uint8_t i2c_byte_address[] = {ENS16X_REG_DATA_ECO2};
    if (i2c_driver_read(ENS16X_I2C_ADDRESS, i2c_byte_address, 1, i2c_data, 2) != ESP_OK) {
        ESP_LOGW("ens16x", "eCO2 read failed");
        ens16x_eco2 = -1;
        return -1;
    }
    uint16_t eco2 = ((uint16_t )i2c_data[0] | (uint16_t)i2c_data[1] << 8);

    ESP_LOGD("ens16x", "ECO2_LSB: %u, ECO2_MSB: %u", i2c_data[0], i2c_data[1]);
    ESP_LOGI("ens16x", "eco2: %hu", eco2);
    ens16x_eco2 = eco2;

    return eco2;
}

int ens16x_read_aqi(void){
    // AQI-S (ENS161 register 0x26) is unused; keep the API for serial compat.
    ens16x_aqi = 0;
    return 0;
}

int ens16x_read_aqi_uba(void){
    uint8_t i2c_data[1];
    memset(i2c_data, 0, 1);
    uint8_t i2c_byte_address[] = {ENS16X_REG_DATA_AQI_UBA};
    if (i2c_driver_read(ENS16X_I2C_ADDRESS, i2c_byte_address, 1, i2c_data, 1) != ESP_OK) {
        ESP_LOGW("ens16x", "AQI-UBA read failed");
        ens16x_aqi_uba = -1;
        return -1;
    }
    int aqi_uba = i2c_data[0] & 0x07;  // AQI-UBA is in bits 0-2

    ESP_LOGI("ens16x", "aqi_uba: %d", aqi_uba);
    ens16x_aqi_uba = aqi_uba;

    return aqi_uba;
}

int ens16x_get_aqi(void){
    return ens16x_aqi;
}

int ens16x_get_aqi_uba(void){
    return ens16x_aqi_uba;
}

int ens16x_get_etvoc(void){
    return ens16x_tvoc;
}

enum ENS_STATUS ens16x_get_status(void){
    return ens16x_status;
}

void ens16x_write_ens210_data(uint8_t * t, uint8_t * h){
    // write envir compensation data to ens16x
    uint8_t i2c_data[5] = {};
    i2c_data[0] = ENS16X_REG_TH_IN;
    i2c_data[1] = t[0];
    i2c_data[2] = t[1];
    i2c_data[3] = h[0];
    i2c_data[4] = h[1];

    // write the regs
    if (i2c_driver_write(ENS16X_I2C_ADDRESS, i2c_data, 5) != ESP_OK) {
        ESP_LOGW("ens16x", "Compensation write failed; VOC output uses stale temp/RH");
        return;
    }

    // read back the temperature and humidity for verification
    uint8_t address[1] = {0x30};
    i2c_data[0] = 0;
    i2c_data[1] = 0;

    i2c_driver_read(ENS16X_I2C_ADDRESS, address, 1, i2c_data, 2);

    for(int i = 0; i < 2; i++){
        ESP_LOGD("ens16x", "temperature i2c_data[%i]: %x", i, i2c_data[i]);
    }
    uint32_t temperature = ((uint32_t)i2c_data[0] | ((uint32_t)i2c_data[1]) << 8) & 0xffff;

    float TinK = (float)temperature / 64; // Temperature in Kelvin
    float TinC = TinK - 273.15; // Temperature in Celsius
    float TinF = TinC * 1.8 + 32.0; // Temperature in Fahrenheit

    ESP_LOGD("ens16x", "%5.1fK %4.1fC %4.1fF", TinK, TinC, TinF);

    // check humidity
    address[0] = 0x32;
    i2c_data[0] = 0;
    i2c_data[1] = 0;
    i2c_driver_read(ENS16X_I2C_ADDRESS, address, 1, i2c_data, 2);

    for(int i = 0; i < 2; i++){
        ESP_LOGD("ens16x", "humidity i2c_data[%i]: %x", i, i2c_data[i]);
    }

    uint32_t humidity = ((uint32_t)i2c_data[0] | ((uint32_t)i2c_data[1]) << 8) & 0xffff;
    float H = (float)humidity/512;
    ESP_LOGD("ens16x", "%2.0f%%", H);


}
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

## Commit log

2025-11-11 all sensors functional
2025-11-11 AQI to color mapping + threading
2025-11-11 ens210 now works in continuous mode. serial protocol added in json format. leds are 30% default brightness
2025-11-14 - Remove get_pulsing_color() from led_color_lib - Add get_pulsing_color_with_intensity() in main.c with intensity support - Update LED control logic to use new local pulsing function - Pulse period c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
2025-11-14 adding button led intensity toggle
2025-11-14 adding nvs functionality to remember the LED intensity the user has chosen
2025-11-14 speeding up the led funciton and adding a hello animation
2025-12-14 adding mechanicals, scripts, kicad files
    [AirCube air wall 11-7-43.3mf, AirCube bottom_prod_12-11.step, AirCube top 20mm PROD.step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]
2026-02-03 adding a aircube_tray windows program. adding one more level of brightness. fixing ens status drivers
    [button.c, ens16x_driver.c, main.c]
2026-03-04 fixing HA pairing and factory reset
    [main.c]
2026-03-06 adding a power setting to zigbee
2026-03-29 Resize partition table for 2MB flash, track in git
    Shrink app partition from 3MB to 1.6MB so the same binary runs on both 2MB and 4MB flash boards. Add gitignore exception for the partition table CSV.
    Made-with: Cursor
    [partitions_zigbee.csv]
2026-04-08 adding SmartThings Edge driver and setup guide
2026-04-08 updating SmartThings channel setup to use driver-channel.json and stuckatprototype tos url
2026-04-08 updating readme, contributing, and smartthings docs for driver-channel.json
2026-04-12 button task needed more ram
2026-04-12 updaing the readme to better explain what the device measures
2026-07-15 Tune auto-dim lux thresholds and retire AQI-S sensor reads.
    Set night enter to 5 lx and day exit to 15 lx with 3-sample debounce, and stop reading ENS161 AQI-S so serial still emits aqi_s:0 for ENS160 compatibility.
2026-07-28 adding mechanicals for the pro
    [AirCube air wall 11-7-43.3mf, AirCube bottom_prod_12-11.step, AirCube top 20mm PROD.step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]
2026-07-29 adding images for the assembly guide
2026-07-29 Adding assembly guides
2026-07-31 Fix auto-dim oscillating between day and night
    The lux fed to auto-dim has the LED's own spill subtracted from it, and
    the spill table over-stated that spill by roughly 4x. On a steady 13.6 lux
    room the compensation reported 2.8 lux at full brightness and 12.7 lux at
    10%, so going night pushed the reading back above the day threshold and
    going day pushed it below the night threshold, cycling every few seconds.
    Re-measure the spill against hardware: stepping between 100% and 10% moves
    the raw ALS reading by ~3 lux, not the ~12.8 lux the old table implied.
    This also removes a ~10 lux under-read from the lux reported over Zigbee
    and BLE whenever the LED was bright.
    Guard against the failure m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
    [auto_dim.c, vcnl4040.c]
2026-08-11 The SCD41 driver now polls data-ready instead of trusting fixed delays, validates and bounds what it decodes, detects a stuck T/RH channel, and attempts a bounded reinit. I2C errors propagate out of 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
    [device_model.c, ens16x_driver.c, ens210.c]
2026-08-12 Add AirCube Web: browser-based flasher and dashboard
    Flashing previously required installing AirCube Tray or hand-driving
    esptool, which is a hard ask for someone who just wants to update a cube
    they bought. This adds a static site, deployed to GitHub Pages, that does
    the same job over Web Serial with nothing to install.
    It mirrors the tray and iOS apps rather than inventing a third look: the
    same colors, thresholds, band scoring and history semantics, ported from
    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
2026-08-12 changing the logic on the SCD measuements to low power mode away from the forced one shot every 30 seconds
2026-08-12 Read firmware versions from tags, not asset filenames
    The v1.4.3 binary was uploaded as AirCube_firmware_v.1.4.3.bin, and since
    the manifest took the version from the filename that stray dot reached the
    flasher's release dropdown as "v.1.4.3". Take the digits from the git tag
    instead, which also copes with the tags being variously Release_v2.0.1,
    Release_V1.5.2 and Release_1.4.2.
    Also move the Pages actions to their Node 24 releases. Nothing was broken,
    but the runner has been forcing the old Node 20 builds onto Node 24 and
    warning about it on every run.
    [build_web_manifest.py]
2026-08-12 Report the firmware version on the serial live frame
    The USB protocol had no way to say what firmware a cube was running, so the
    web app could only show a version when it had flashed that cube itself and
    otherwise admitted it did not know. Add an "fw" key to the periodic frame,
    read from the same app descriptor that BLE and Zigbee already report, so
    every serial client picks it up with no handshake and older units simply
    omit the key.
    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
2026-08-12 Make Disconnect actually forget the cube
    Closing the link left the browser's port permission untouched, so
    getPorts() handed the cube straight back on the next load and init()
    re-adopted it: disconnecting and refreshing brought it back, connected.
    Revoke the grant with SerialPort.forget() and drop the device from the
    registry. Reconnecting now goes through the browser picker again, which
    is what forgetting a device is supposed to mean.
    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
2026-08-12 Show a fetching state while history syncs
    A full pull is a few thousand entries and takes seconds, during which the chart
    sat empty under "No history for this range" - indistinguishable from a device
    that returned nothing. Put a spinner, "Fetching data" and a live entry count in
    the middle of the chart area, and suppress the empty message while a sync is in
    flight.
2026-08-12 serial protocol bug fix
    [serial_protocol.c]
2026-08-12 Reboot the cube after flashing, and stop listing phantom cubes
    esptool-js implements hard_reset as "wait, then set RTS false", which only
    releases a reset line an external USB-UART bridge was already holding. The cube
    talks over the ESP32-H2's built-in USB Serial/JTAG, where EN has to be strobed,
    so nothing reset it and it sat in download mode until physically unplugged.
    Strobe it instead, with DTR low so IO0 is released and the application boots
    rather than the bootloader.
    The cube also reports no USB serial number, so the browser cannot recognise it
    after it re-enumerates: every reset yields a new SerialPort and a new permission
    grant. getPorts() then returns dead grants, which were liste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
2026-08-12 List a cube only once its port opens
    Skipping ports that report connected === false was the wrong filter. The stale
    permission grants a cube leaves behind on every re-enumeration all point at the
    same hardware, so once it is plugged back in they all report as connected. Only
    the first port opens; the operating system refuses the rest, and those refusals
    were being listed as ghost cubes.
    Adopt a port only after it opens, retrying briefly since a cube that has just
    enumerated can refuse the first attempt. A port the browser will not open is not
    a cube anyone can use, whatever the reason. An explicit pick through the browser
    picker still surfaces the failure rather than silently dropping it.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
2026-08-20 Keep LED stable through Zigbee recovery
    Retain visual and SCD41 state across warm resets, remove the reconnect cue, and release firmware 2.0.4.
    [auto_dim.c, main.c, scd41.c]
2026-08-21 Add CO2 fresh-air calibration to the web app
    Pro cubes no longer self-calibrate their SCD41, so the web app needs a way to set the current air to 425 ppm: an on-demand entry in the device menu and settings, plus a one-time prompt after a cube is upgraded from 2.0.4 or older.
2026-08-23 Release firmware v2.0.5 with SCD41 ASC disable and FRC calibration
    Disable automatic self-calibration on Pro, add 425 ppm forced recalibration
    with one-time post-upgrade prompting, persist settled FRC state in the web
    app across reflashes, and update docs for Base vs Pro and new serial commands.
2026-08-23 Detect and recover an SCD41 that stops reporting CO2
    A Pro whose CO2 channel had failed reported "CO2 UNAVAILABLE" indefinitely
    with nothing to diagnose from. A frame carrying good temperature and humidity
    but a rejected CO2 word counted as a successful read, so the shared failure
    counter reset every cycle, recovery never ran, and health reported fails 0
    after hundreds of bad frames.
    Count CO2 failures separately, and after five consecutive such frames run the
    sensor's built-in self test once before falling back to stop/reinit recovery.
    The self test is the only on-device check that distinguishes an internal
    malfunction from a supply that cannot hold up under measurement peaks; on the
    affec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
    [scd41.c, serial_protocol.c]
2026-08-31 adding STL and STEP files for aircube pro and base
    [AirCube air wall 11-7-43.3mf, AirCube bottom_prod_12-11.step, AirCube top 20mm PROD.step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]
2026-09-02 upding the serial protocol to not stall out
    [serial_protocol.c]
2026-09-21 pro kicad files
    [AirCube v1.0 BOM.csv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]
2026-09-29 web: support cubes on pre-February-2026 firmware
    Firmware shipped through January 2026 reads commands from UART0 and only
    prints to USB-Serial/JTAG, so every command sent over USB is ignored and,
    after 64 bytes, the H2's RX FIFO is full and host writes hang forever.
    The web app timed out on history sync, silently dropped brightness and
    settings, and could wedge on a write.
    - devices.js: probe get_config within a 63-byte budget; mark the cube
    legacy when it streams but never answers, and stop writing to it.
    - serial.js: write-stall watchdog and a bounded close() so the flasher
    can still take the port.
    - views: "Firmware update needed" card with an Update firmware button,
    controls that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
